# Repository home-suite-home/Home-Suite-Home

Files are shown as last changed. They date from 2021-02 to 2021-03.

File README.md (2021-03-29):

# Home-Suite-Home

# Product Vision
  Our product, Home Suite Home is for anyone that lives in a home or manages properties remotely. With our product, users can track a multitude of metrics inside and out of the home. As well as, have the piece of mind their investment is protected with real time alerts when anything out of the ordinary occurs. Great for when the user cannot be there in person. Home Suite Home supplies a wide range of sensing devices covering the environment and health of the home. The sensors and software are designed using off the shelf components and open source software to allow for easy access and infinite customizability. Our product differs from competitors such as Nest and SensorSuite by placing a focus on overall property health. It would focus more on providing analytics on the usage of utilities that are found inside the home, providing the potential to catch issues before they occur, saving the user from expensive repairs. This is the perfect tool for property or building managers, homeowners and even hobbyists to take control over their home’s data and bring it all together in one convenient, powerful place.

  ## Team Members
  * Matthew Dowdy - dowdyma1
  * Andres Graterol - graterollin
  * Wyatt Vining - wv040
  * David Crumley - daviejones
  * Nathan Moulton - NathanM117

# Sprint 1

## Materials
* [Trello Board](https://trello.com/b/BFcwvt3p/project) (Backlogs and Requirements)
* [Requirements](artifacts/requirements.md)
* [Velocity Chart](https://docs.google.com/spreadsheets/d/1tpRyT-jUgHkrLnwx5NcxtOvh3uGg8ddGYrl60E0q6DA/edit#gid=0)
* [Burndown Chart for Sprint 1](https://docs.google.com/spreadsheets/d/1tpRyT-jUgHkrLnwx5NcxtOvh3uGg8ddGYrl60E0q6DA/edit#gid=2030454987)

## Task Allocation
* Andres Graterol (graterollin) - requirement chart
* David Crumley (daviejones) - velocity chart
* Matthew Dowdy (dowdyma1) - burndown chart
* Wyatt Vining (wv040) - Trello Board
* Nathan Moulton (NathanM117) - product backlog

# Sprint 2

## Materials
* [Trello Board](https://trello.com/b/BFcwvt3p/project) (Backlogs and Requirements)
* [Velocity Chart](https://docs.google.com/spreadsheets/d/1tpRyT-jUgHkrLnwx5NcxtOvh3uGg8ddGYrl60E0q6DA/edit#gid=0)
* [Burndown Chart for Sprint 2](https://docs.google.com/spreadsheets/d/1tpRyT-jUgHkrLnwx5NcxtOvh3uGg8ddGYrl60E0q6DA/edit#gid=1102031550)
* [System Architecture](artifacts/architecture.md)
* [Product Demonstration](https://youtu.be/opssn2ocK3U)

## Task Allocation
* Andres Graterol (graterollin) - Requirement Chart/ UI
* David Crumley (daviejones) - Architecture/Class Diagrams
* Matthew Dowdy (dowdyma1) - UI / Velocity & Burndown Charts / Design Doc
* Wyatt Vining (wv040) - Sensor Prototype / Demo Video / Architecture
* Nathan Moulton (NathanM117) - Design Doc/Architecture Diagrams

# Sprint 3

## Materials
* [Trello Board](https://trello.com/b/BFcwvt3p/project) (Backlogs and Requirements)
* [Velocity Chart](https://docs.google.com/spreadsheets/d/1tpRyT-jUgHkrLnwx5NcxtOvh3uGg8ddGYrl60E0q6DA/edit#gid=0)
* [Burndown Chart for Sprint 3](https://docs.google.com/spreadsheets/d/1tpRyT-jUgHkrLnwx5NcxtOvh3uGg8ddGYrl60E0q6DA/edit#gid=571215391)
* [System Architecture](artifacts/architecture.md)
* [Testing](https://github.com/home-suite-home/Home-Suite-Home/tree/main/testing)
* [Product Demonstration](https://youtu.be/FdkxHIFB3po)

## Task Allocation
* Andres Graterol (graterollin) - Automated unit tests / Requirements
* David Crumley (daviejones) - EmailComponent / EmailCommandHandler
* Matthew Dowdy (dowdyma1) - UI / Charts
* Wyatt Vining (wv040) - Sensor Values Intake / Demo Video
* Nathan Moulton (NathanM117) - Database Setup and Testing

# Sprint 4

## Materials
* [Trello Board](https://trello.com/b/BFcwvt3p/project) (Backlogs and Requirements)
* [Velocity Chart](https://docs.google.com/spreadsheets/d/1tpRyT-jUgHkrLnwx5NcxtOvh3uGg8ddGYrl60E0q6DA/edit#gid=0)
* [Burndown Chart for Sprint 4](https://docs.google.com/spreadsheets/d/1tpRyT-jUgHkrLnwx5NcxtOvh3uGg8ddGYrl60E0q6DA/edit#gid=1480462962)
* [System Architecture](artifacts/architecture.md)
* [Testing](https://github.com/home-suite-home/Home-Suite-Home/tree/main/testing)
* [Product Demonstration](https://youtu.be/R36tOa5FSI4)

## Task Allocation
* Andres Graterol (graterollin) - Automated & Manual Testing
* David Crumley (daviejones) - Email Sensor Data Reporting
* Matthew Dowdy (dowdyma1) - UI & Charts
* Wyatt Vining (wv040) - Demo Video / Sensor Config / Raspberry Pi Setup
* Nathan Moulton (NathanM117) - Database Functionality & Testing

# Sprint 5

## Materials
* [Trello Board](https://trello.com/b/BFcwvt3p/project) (Backlogs and Requirements)
* [Velocity Chart](https://docs.google.com/spreadsheets/d/1tpRyT-jUgHkrLnwx5NcxtOvh3uGg8ddGYrl60E0q6DA/edit#gid=0)
* [Burndown Chart for Sprint 5](https://docs.google.com/spreadsheets/d/1tpRyT-jUgHkrLnwx5NcxtOvh3uGg8ddGYrl60E0q6DA/edit#gid=994440609)
* [System Architecture](artifacts/architecture.md)
* [Testing](https://github.com/home-suite-home/Home-Suite-Home/tree/main/testing)
* [Product Demonstration](https://youtu.be/gygcMzER3ZE)

## Task Allocation
* Andres Graterol (graterollin) - Automated Testing (UI & timeKeeper) / Manual Testing (Database)
* David Crumley (daviejones) - Data analytics email response (in development)
* Matthew Dowdy (dowdyma1) - UI
* Wyatt Vining (wv040) - Raspberry Pi upgrade / Database Stress Test / Timestamps / Sensor Config Data / Sensor Polling - Save Data / Sample Database Creation
* Nathan Moulton (NathanM117) - Database.py/ Manual Testing (Database)/ Sample Database Creation/ Timestamps

## Quick Links
* [System Source Code](source)
* [Sensor Source Code](sensor_source)
* [Testing](testing)
* [User Interface](source/email_ui.py)

# Sprint 6

## Materials
* [Trello Board](https://trello.com/b/BFcwvt3p/project) (Backlogs and Requirements)
* [Velocity Chart](https://docs.google.com/spreadsheets/d/1tpRyT-jUgHkrLnwx5NcxtOvh3uGg8ddGYrl60E0q6DA/edit#gid=0)
* [Burndown Chart for Sprint 6](https://docs.google.com/spreadsheets/d/1tpRyT-jUgHkrLnwx5NcxtOvh3uGg8ddGYrl60E0q6DA/edit#gid=428674570)
* [System Architecture](artifacts/architecture.md)
* [Testing](https://github.com/home-suite-home/Home-Suite-Home/tree/main/testing)
* [Product Demonstration](https://youtu.be/VESqYKWHarw)

## Task Allocation
* Andres Graterol (graterollin) - Developed and updated Automated Tests / Manual Testing
* David Crumley (daviejones) - Analytics / Email Response
* Matthew Dowdy (dowdyma1) - UI / Charts
* Wyatt Vining (wv040) - Encryption / Sensor Header Files / Manual Testing
* Nathan Moulton (NathanM117) - Development and Testing for Database

## Quick Links
* [System Source Code](source)
* [Sensor Source Code](sensor_source)
* [Testing](testing)
* [User Interface](source/User_Interface.py)

# Sprint 7

## Materials
* [Trello Board](https://trello.com/b/BFcwvt3p/project) (Backlogs and Requirements)
* [Velocity Chart](https://docs.google.com/spreadsheets/d/1tpRyT-jUgHkrLnwx5NcxtOvh3uGg8ddGYrl60E0q6DA/edit#gid=0)
* [Burndown Chart for Sprint 7](https://docs.google.com/spreadsheets/d/1tpRyT-jUgHkrLnwx5NcxtOvh3uGg8ddGYrl60E0q6DA/edit#gid=1633691467)
* [System Architecture](artifacts/architecture.md)
* [Testing](https://github.com/home-suite-home/Home-Suite-Home/tree/main/testing)
* [Product Demonstration](https://youtu.be/Fo_0uUr3R5Y)

## Task Allocation
* Andres Graterol (graterollin) - Developed and updated Automated Tests
* David Crumley (daviejones) - Email_Driver / Interactive Graphs
* Matthew Dowdy (dowdyma1) - UI / Charts
* Wyatt Vining (wv040) - Sensor Email Alerts / Conversions / Global Settings / Sensor Creation and Modeling / Demo Video
* Nathan Moulton (NathanM117) - Database.py / Install Scripts

## Quick Links
* [System Source Code](source)
* [Sensor Source Code](sensor_source)
* [Testing](testing)
* [User Interface](source/User_Interface.py)

# Sprint 8

## Materials
* [Trello Board](https://trello.com/b/BFcwvt3p/project) (Backlogs and Requirements)
* [Velocity Chart](https://docs.google.com/spreadsheets/d/1tpRyT-jUgHkrLnwx5NcxtOvh3uGg8ddGYrl60E0q6DA/edit#gid=0)
* [Burndown Chart for Sprint 8](https://docs.google.com/spreadsheets/d/1tpRyT-jUgHkrLnwx5NcxtOvh3uGg8ddGYrl60E0q6DA/edit#gid=335631044)
* [System Architecture](artifacts/architecture.md)
* [Testing](https://github.com/home-suite-home/Home-Suite-Home/tree/main/testing)
* [Product Demonstration](https://youtu.be/5nkZvYmcQeU)

## Task Allocation
* Andres Graterol (graterollin) - Automated Unit Tests / Project Presentation PowerPoint 
* David Crumley (daviejones) - installation and run script / Bug Fixes
* Matthew Dowdy (dowdyma1) - UI / Charts
* Wyatt Vining (wv040) - Sensor 3D Models / Sensor Arduino Code / Bug Fixes / Product Demo Video
* Nathan Moulton (NathanM117) - Database + Testing

## Quick Links
* [System Source Code](source)
* [Sensor Source Code](sensor_source)
* [Testing](testing)
* [User Interface](source/User_Interface.py)

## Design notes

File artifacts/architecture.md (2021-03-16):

# Program Organization
Home-Suite-Home is an open-source sensor suite. It is designed to be lightweight, modular home
analytics suite that provides home-owners and property managers a platform to monitor the health of their properties through the useof smart sensors. On a high level of operation, the sensors are responsible for sending data to a localised database hosted by a server/agregator. The sever portion stores data for time-series representaton, and the aggregator portion observes values in real time to verify that sensor readings are within user defined parameters. The user will recieve notfications via email in the event of any data anomalies, or when requested for data snapshots or historical data.

# Code Design
## System Context Diagram
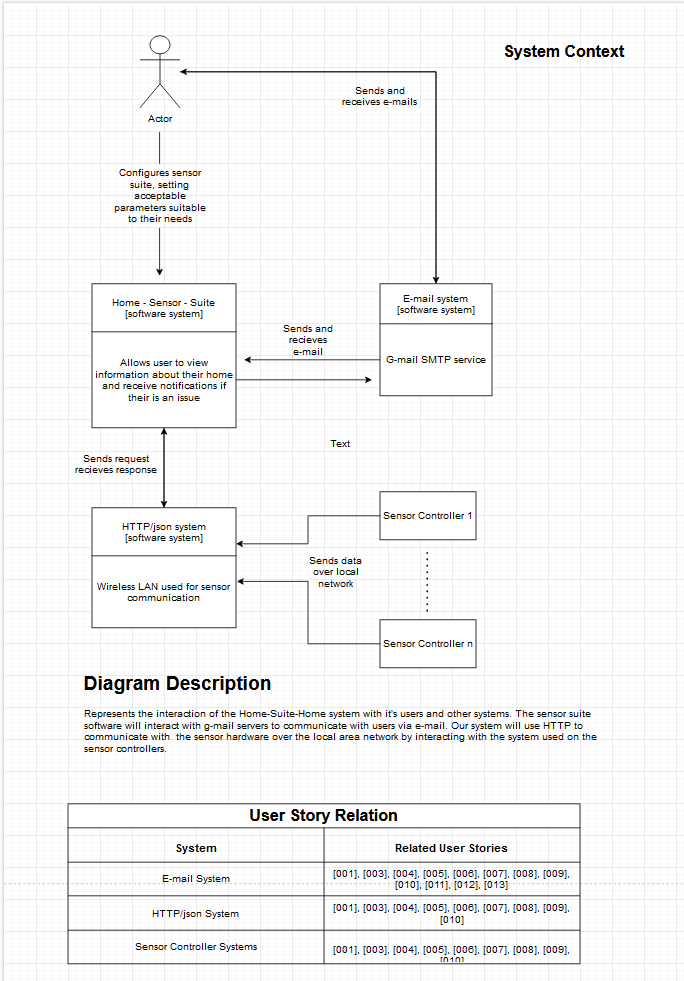
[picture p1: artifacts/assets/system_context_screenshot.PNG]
screenshot of system context diagram


## Container Diagram
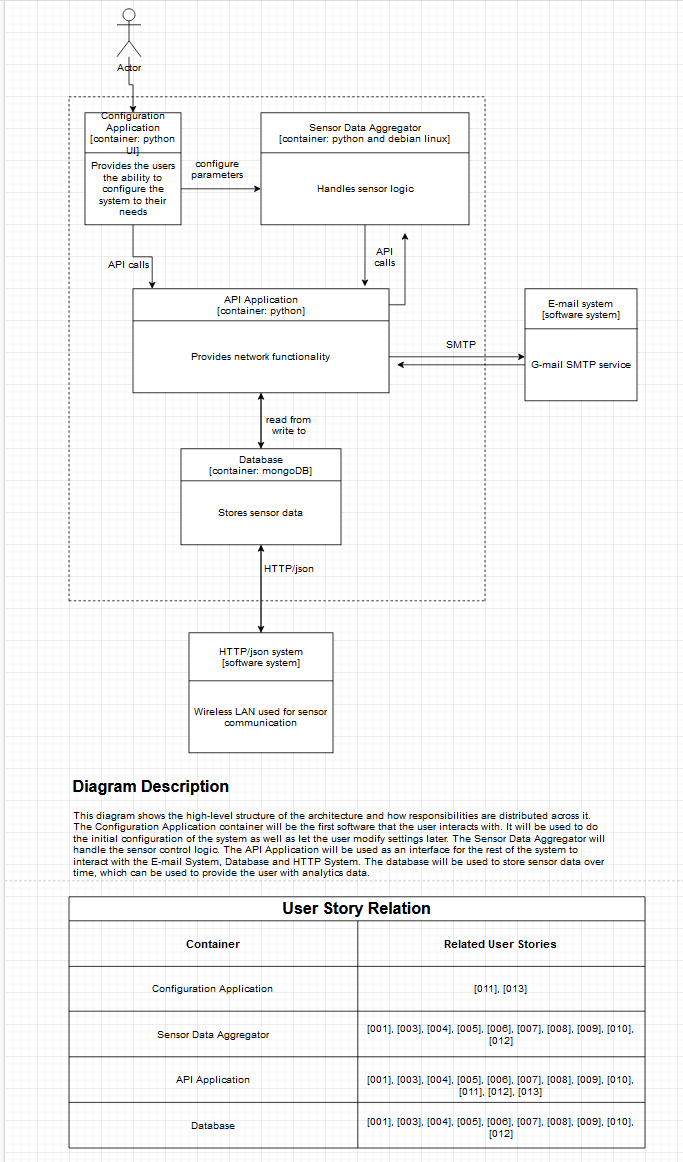
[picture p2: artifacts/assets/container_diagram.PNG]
screenshot of container diagram


## Component Diagrams
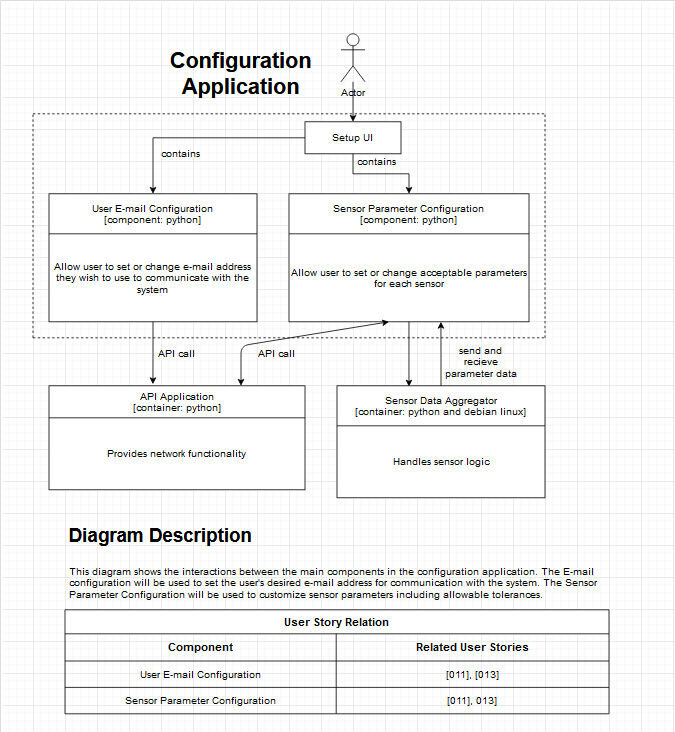
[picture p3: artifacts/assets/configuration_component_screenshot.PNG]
screenshot of configuration application

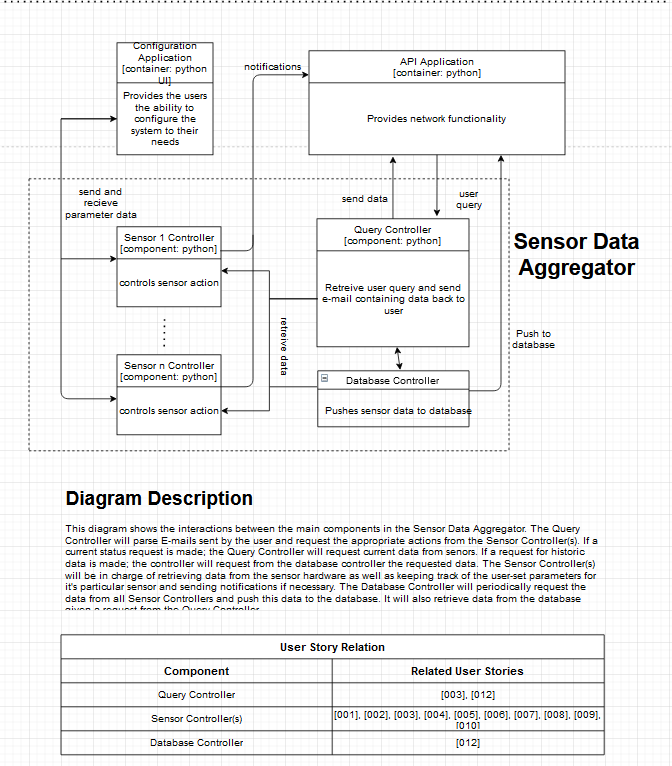
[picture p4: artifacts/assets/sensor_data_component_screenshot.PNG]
screenshot of sensor data aggregator

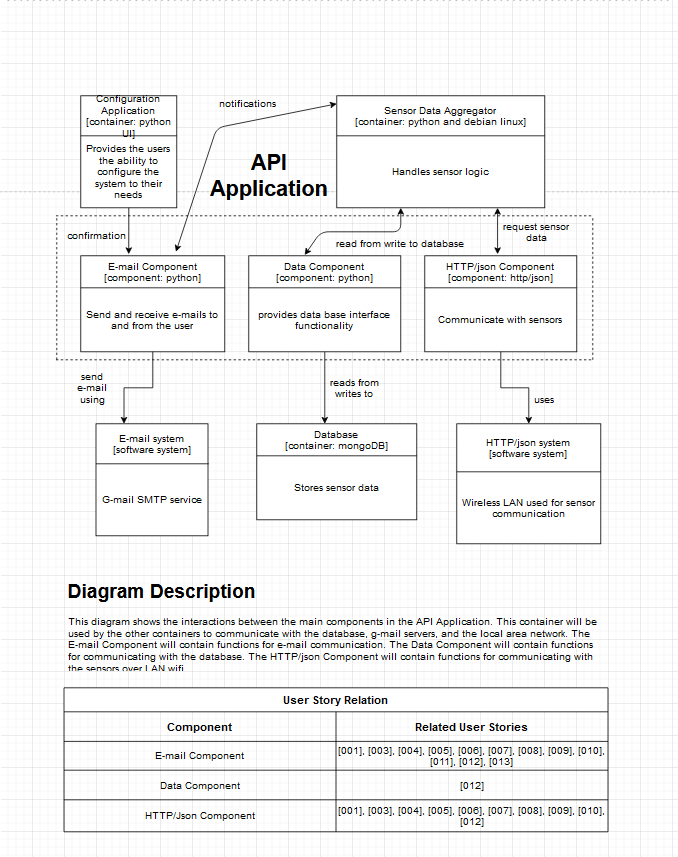
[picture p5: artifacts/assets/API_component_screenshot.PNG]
screenshot of API


## Class Diagrams
### EmailComponent
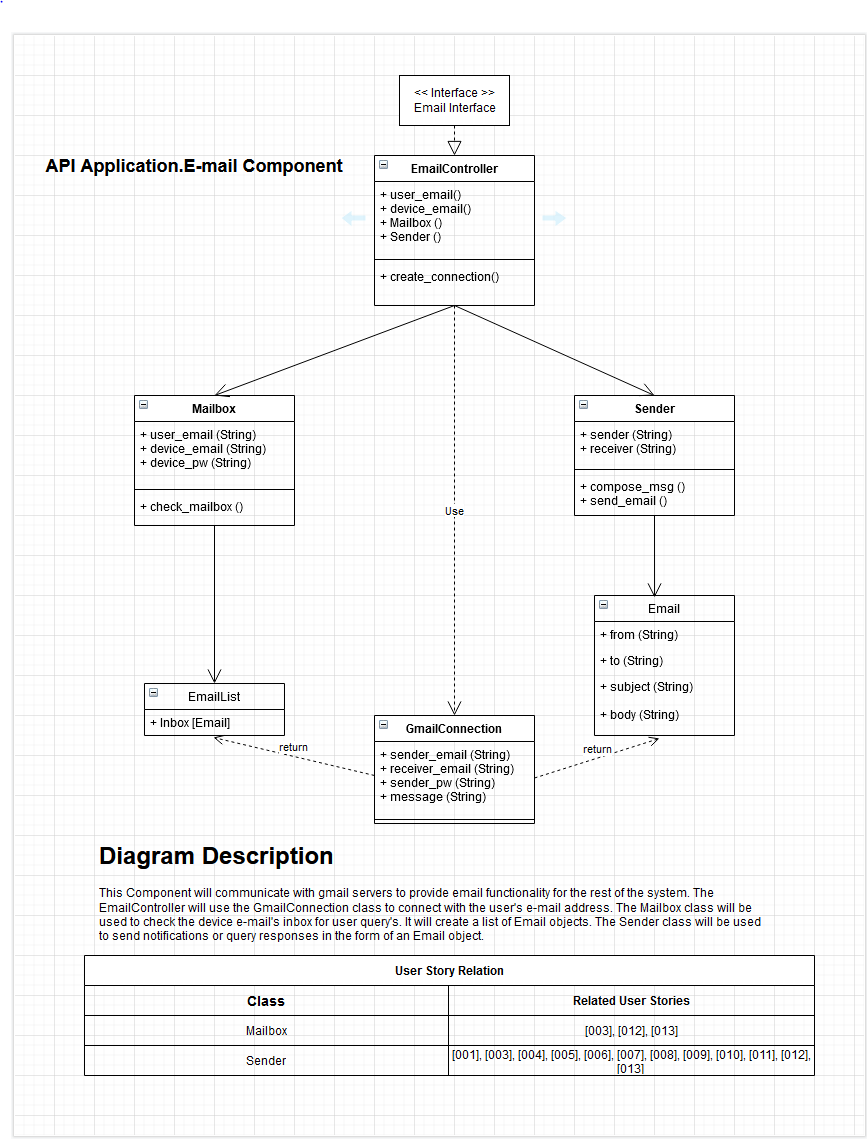
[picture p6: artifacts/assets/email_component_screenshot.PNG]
screenshot of email component class diagram

### EmailCommandHandler
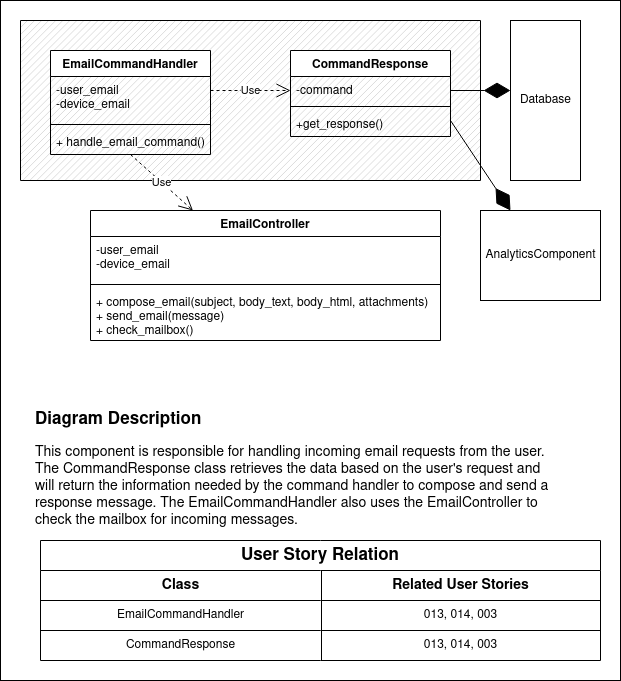
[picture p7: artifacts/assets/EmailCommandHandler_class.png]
screenshot of EmailCommandHandler class diagram

### AnalyticsComponent
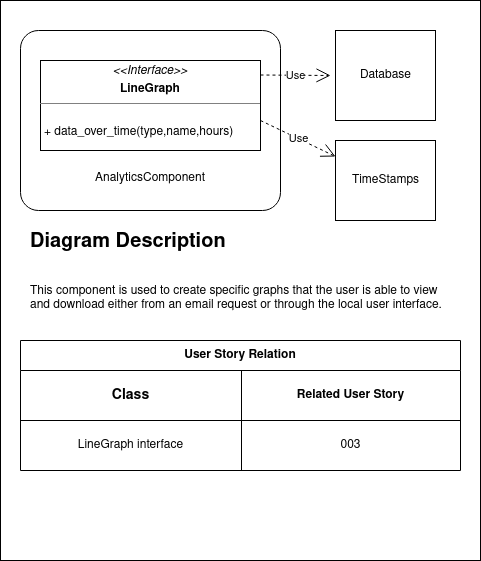
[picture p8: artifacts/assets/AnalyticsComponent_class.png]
screenshot of AnalyticsComponent class diagram

### Sensors.py
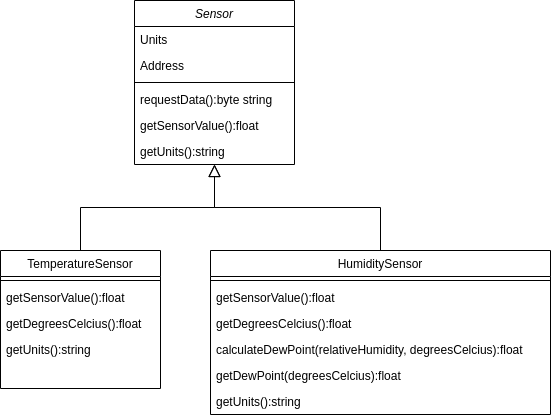
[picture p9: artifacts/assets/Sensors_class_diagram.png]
Screenshot of Sensors.py class Diagram

#### Diagram Description:
This component is used to retrieve sensors data over the network. The Sensors class is responsible for requesting the base data of any sensor. The TemperatureSensor and HumiditySensor classes extend the functionality of the Sensor class and provide specific units and conversions based on the type of data received.
| Class | Related User Stories (UID) |
| --- | --- |
| Sensor | 002, 017, 022 |
### timeKeeper.py
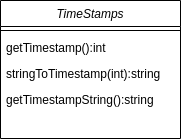
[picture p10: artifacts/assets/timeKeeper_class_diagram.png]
Screenshot of timeKeeper.py class Diagram

#### Diagram Description:
This component provides utilities for parsing and using time and date stamps. The function getTimestamp() returns an integer value representing the current time. This is useful as a format for storing the timestamp in the database. Then we can use stringToTimestamp() to convert the stored timestamp back into a readable format.
| Class | Related User Stories (UID) |
| --- | --- |
| TimeStamps | 020 |
### encryption.py
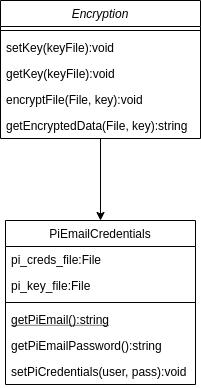
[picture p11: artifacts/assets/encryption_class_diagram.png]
Screenshot of timeKeeper.py class Diagram

#### Diagram Description:
The class encryption provides functions to generate, store and retrieve a secure key. Also, encrypt and decrypt a file using the secure key. The PiEmailCredentials class extends that functionality to specifically save and retrieve the email credentials for the Pi itself.
| Class | Related User Stories (UID) |
| --- | --- |
| TimeStamps | 028 |

# Data Design
Much of the data stored in this database will be unstructured. Sensors like the temperature/humidity sensor won't have many relations with one another. There are some sensor types that may have relational attributes, such as the RFID sensors which will require a table of valid IDs...

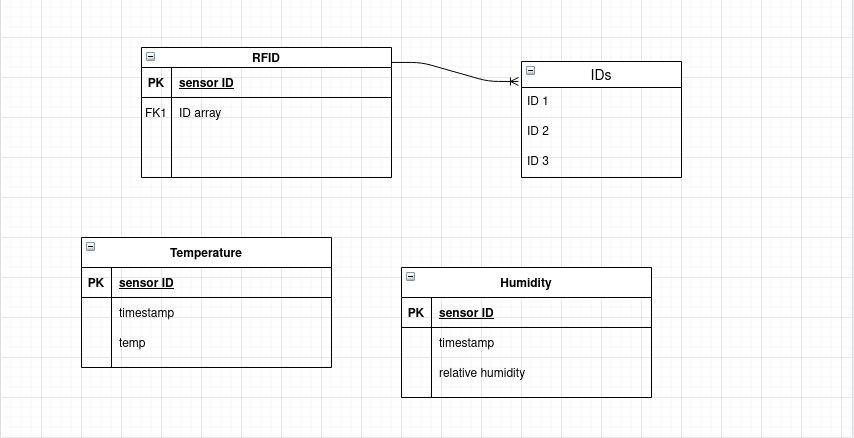
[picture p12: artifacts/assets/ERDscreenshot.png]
screenshot of ERD


# Business Rules
- The system should record new sensor data every 30 seconds.
- The user should be able to add new sensors after initial setup through the GUI.
- The system should be able to store at least a year's worth of sensor data. This should be
calculated with a 'standard' sensor collection.

# User Interface Design
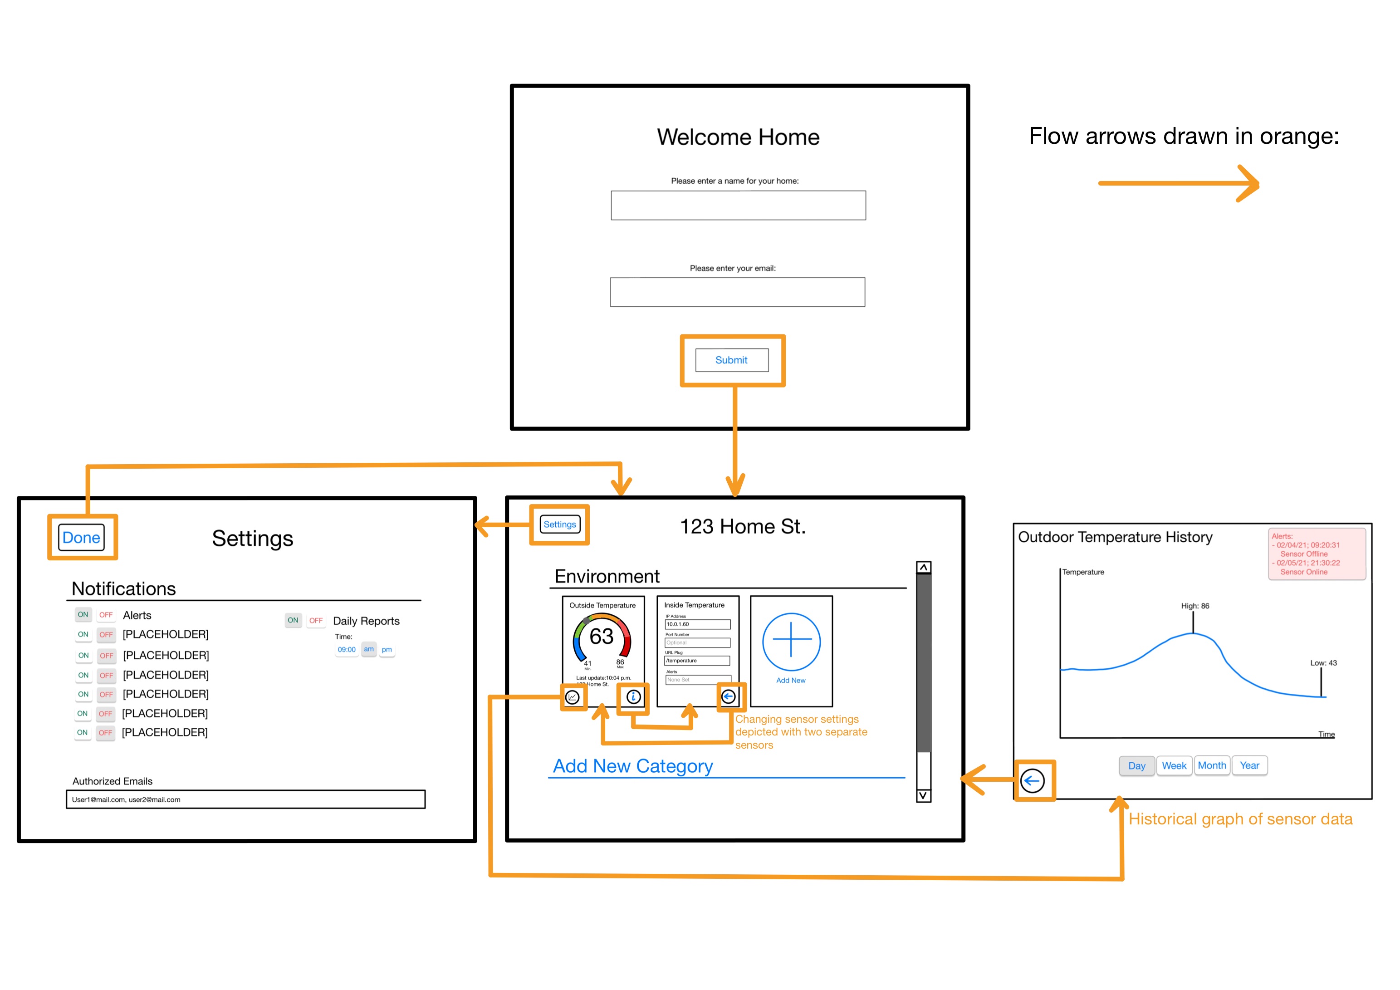
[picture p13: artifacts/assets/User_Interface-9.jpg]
UI Map Diagram

The purpose of this screen is to get the user's email so that the Raspberry
Pi knows where to send updates and statistics about the user's system.

After plugging in the Raspberry Pi to power and ethernet, the user makes sure they are on the same wifi network as the RaspberryPi and types in the
IP address `127.0.0.1:8050` into their browser. The user then uses the mouse to click on the text box, and then they type their
email. Once the user presses submit, a confirmation email is sent to the user so that they know that sending an email works.

| Window Number | UID |
|---|-----|
| 1 | 011 |

# Resource Management
Computational load is divided among several ESP8266 modules with 2.5GHz processors, and a
Raspberry Pi 3 with 2Gb of RAM. The Pi is responsible for running the main script for the aggregator, hosting the GUI and related config files, as well as hosting the database for the sensors. Further research is needed to determine the exact workload and resource requirements.

# Security
This solution is designed to focus on ease of access and utility to the open-source community.
That said software security is not a primary concern for our implementation. The architecture of the system however, lends itself to being rather secure in practice. All traffic occurs over the local network, and so the data saved within the database is not seen except by those on said network.

# Performance
Our system is designed to run using low cost hardware such as, Raspberry Pi's. With recent advancements in these types of computers, performance should not be a concern. Our limitations may be considered as the hardware limitations of the entry level Raspberry Pi ([Technical Specifications](https://www.raspberrypi.org/products/raspberry-pi-4-model-b/specifications/)). Further, our system is designed to use a polling approach to sensor data collection. Meaning, the data can be collected and analyzed at the rate the aggregator (Raspberry Pi) becomes available. Lastly, the NodeMCU ESP8266 boards used to send sensor data should only be required to send their data at most every seccond which is well within their performance capabilities.

# Scalability
The user will be able to add extra sensors up to a point, so as to provide greater breadth of analytics. The open source nature of our system lends itself to creating potentially limitless additional sensors and control systems. A single instance of the system can serve only proprty due to the localised nature of operation. Multiple properties may be monitored by setting up an aggregator server at each loction.

# Interoperability
The sensors are responsible for sharing data with the database as well at the aggregator. The aggregator is responsible for receiving and responding to email requests from a user.

# Internationalization/Localization
Our implimentation is localized. All string handling will be ASCII and English. This may be modified in the future as the software is open source.

# Input/Output
The primary input/output(I/O) for our system will be HTTP requests between the aggregator and sensor modules. The I/O will be real-time. When a request is made, the receiver processes and sends a response to the requester. If the response is unexpected, the aggregator will handle the error as appropriate.

# Error Processing
This solution focuses on monitoring sensor data and keeping the user informed. Should an error occur, the system may first attempt to correct it. For example, if a sensor does not respond, the request may be resent. In the case the error may not be corrected, the user will be notified via email and may take appropriate action. Also, any important information will be logged to a local file on the aggregator should an error occur.

# Fault Tolerance
The system is designed to continue to run through a multitude of faults. For example, if a sensor is unavailable or not working properly, the aggregator will continue to log all other sensors and check periodically to see if the issue with that sensor has been resolved. The system may also enter an alternate method of operation given a critical failure. As long as the aggregator is powered on and connected to the network, a user may still request email reports from the system. These reports may be ammended to reflect errors in the system.

# Architectural Feasibility
The architecture of our system is intended to grow into future features. This allows the architecture design to start out as feasible. With room to add features as the core system is developed.

# Overengineering
Our system is designed to continue to run through many issues. There is a one single point failure: the aggregator. If the aggregator encounters a hardware or power failure, the system will no longer function as intended. It is important to note that even without the aggregator the sensors can still be queried by HTTP requests from within the network.

# Build-vs-Buy Decisions
### Libraries Used
* Dash
* ESP8266WiFi
* ESP8266WebServer
* Wire
* Adafruit_SHT31

*This section will continue to be updated as more code is added with the sprints to come...*

# Reuse
We intend to use some open source libraries mentioned in the Build-vs-Buy Decisions. This code, where possible, will be built into functions that can be replaced in the event we pivot to different libraries. Beyond that, we currently have no intention to reuse code. This is subject to change as we progress though the design process. We will update this document should any changes arise.

*italic* This section will continue to be updated as more code is added with the sprints to come...

# Change Strategy
The system is intended to be modular and adaptable. New sensors and their data can be added simply at any point in the future. We also intend to build the core functionality in a way that allows the base system to persist through many different perturbations of the higher level features. This will be accomplished by using simple, single responsibility functions and delineating data files between versions.

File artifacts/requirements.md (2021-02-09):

# Requirements 

| Requirement ID | User Story ID | Requirement | Acceptance Criteria | Effort | Priority | Status |
|---|---|---|---|---|---|---|
| 000 | DEV 001 | The burndown chart shall contain an "ideal line" of 45 degrees  | The "ideal line" is present and is at a downward 45 degree slope from the top left of the chart | 2 | Necessary | Verified |
| 001 | DEV 001 | The burndown chart shall contain the actual line depicting the team's work in a weekly sprint | The actual line is present and accurately depicts the work done by the team during the sprint | 2 | Necessary | Verified |
| 002 | DEV 001 | The burndown chart will have a y-axis that consists of the story points per sprint | The burndown chart has a y-axis consisting of the story points | 2 | Necessary | Verified |
| 003 | DEV 001 | The burndown chart will have an x-axis that consists of the number of days per sprint | The burndown chart has an x-axis consisting of the number of days per sprint | 2 | Necessary | Verified |
| 004 | DEV 002 | The velocity chart shall have a column for planned amount of story points to be completed during the sprint | The velocity chart has a column for the planned amount of story points to be completed during the sprint | 1 | Necessary | Verified |
| 005 | DEV 002 | The velocity chart shall have a column for the actual amount of story points to completed during the sprint | The velocity chart has a column for the actual amount of story points to completed during the sprint | 1 | Necessary | Verified |
| 006 | DEV 002 | The velocity chart will have a y-axis that consists of the number of story points planned for the sprint | The velocity chart has a y-axis consisting of the number of story points planned for the sprint | 1 | Necessary | Verified |
| 007 | DEV 002 | The velocity chart will have an x-axis that consists of the sprint number | The velocity chart has an x-axis consisting of the sprint number | 1 | Necessary | Verified |
| 008 | DEV 003 | The developers shall set up a virtual linux environment | All developers can run and push a simple "hello, world" program | 1 | Necessary | Verified |
| 009 | DEV 004 | The requirements chart shall have columns for: Requirement ID, User Story ID, Requirement, Acceptance Criteria, Efffort, Priority, and Status | The requirements chart has columns for the specified elements | 1 | Necessary | Verified |
| 010 | DEV 005 | The trello board shall reflect the product backlog | The trello board contains the product backlog | 1 | Necessary | Verified |
| 011 | DEV 005 | The trello board shall reflect the sprint backlog | The trello board contains the sprint backlog | 1 | Necessary | Verified |
| 012 | DEV 005 | The trello board shall contain columns for keeping updates such as: planning, working, testing, and done | The trello board contains columns for planning, working, testing, and done | 1 | Necessary | Verified |
| 013 | DEV 006 | The developers shall create a smtp hello world program | When the script is run an email is created and sent out | 2 | Necessary | Verified |  
| 014 | DEV 007 | New burndown and velocity charts shall be made for sprint 2 | The new sprint 2 burndown and velocity charts have been created, and are available to access from github | 1 | Necessary |  Verified |
| 015 | DEV 008 | The architecture diagram shall contain context, container, and component diagrams | The architecture diagram is comprised of context, container, and component diagrams | 3 | Necessary | Verified |
| 016 | DEV 008 | The architecture diagram shall include a description and explanation of each diagram within it | The architecture diagram includes a description and explanation of each diagram within it | 3  | Necessary | Verified |
| 017 | DEV 008 | The architecture diagram shall include a table that relates each block to one or more user stories | The architecture diagram includes a table that relates each block to one or more user stories | 3 | Necessary | Verified |
| 018 | DEV 009 | The UML class diagram shall display the classes along with the interactions between them | The UML class diagram displays the classes along with the interactions between them | 2 | Necessary | Verified |
| 019 | DEV 009 | Each UML diagram shall be accompanied by a brief description explaining what the elements are and why they are in the diagram | Each UML diagram is accompanied by a brief description explaining what the elements are and why they are in the diagram | 2 | Necessary | Verified |
| 020 | DEV 009 | The class diagram shall include a table that relates each class to one or more user stories | The class diagram includes a table that relates each class to one or more user stories |  2 | Necessary | Verified |
| 021 | DEV 010 | The complete design document shall include elaboration for business rules, resource management, security, performance, scalability, interoperability, internationalization/localization, input/output, error processing, fault tolerance, architectural feasability, overengineering, build-vs-buy decisions, reuse, and chang strategy | The complete design document has all fields covered and is shown in github |  4 | Necessary | Verified |
| 022 | DEV 011 | The temperature sensor hooked up to the ESP8266 shall output data on a web browser | The sensor value information can be viewed from a web browser within the Local Area Network |  2 | Necessary | Verified |
| 023 | 011 | The user interface shall be able to register a user's email information | The user will receive an email confirmation | 4 | Necessary | Verified |
| 024 | DEV 013 | The video demonstration shall showcase the temperature sensor and a basic UI | The video demonstrates the functionality of the temperature sensor and a basic UI in roughly two minutes | 2 | Necessary | Verified |

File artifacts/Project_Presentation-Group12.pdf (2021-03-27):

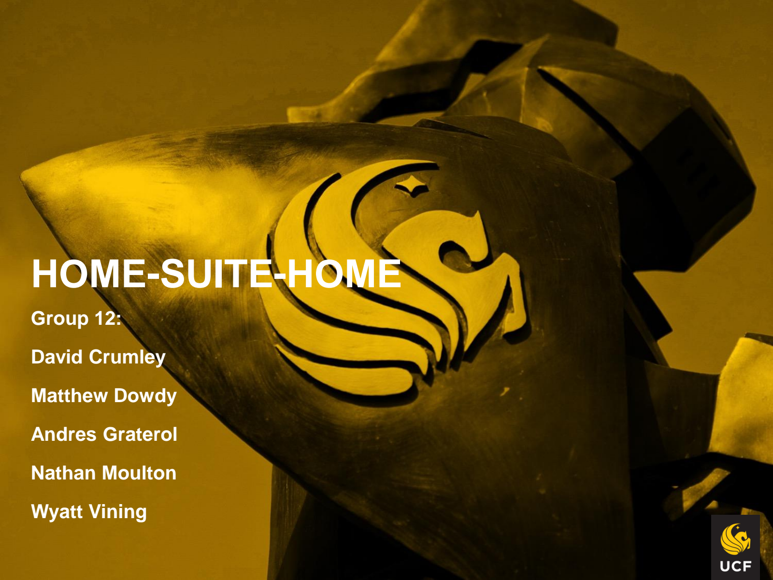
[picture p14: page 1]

# HOME-SUITE-HOME

Group 12:

David Crumley

Matthew Dowdy

Andres Graterol

Nathan Moulton

Wyatt Vining

# Purpose & Motivation

Home-Suite-Home was designed with the intention of providing a method for property owners to remotely view the status of their properties. The properties would be installed with multiple sensors that could be easily accessed using a User-Interface and email system. With Home-Suite-Home installed into the homeowner’s properties, the customer would never have to worry about what is happening while they are away!

# System Alternatives

Our Competitors:
- Google Nest Hub
- This system provides an interconnection of smart devices around the home. Google Hub has compatibility with devices such as security cameras, smart lights, and speakers.
- Samsung SmartThings Hub
- This system provides an interconnection of smart devices around the home. It comes with a companion mobile application and allows for the addition of other Samsung brand smart devices such as motion sensors and water leak detectors.
Us:
Since our system is open-source, it eliminates the need for such high installation and maintenance costs associated with the competition. There is no subscription necessary, and users have the ability to configure and add their own sensors. Unlike our competitors, Home-Suite-Home allows the user to add sensor of any type. In comparison to the other systems, our sensor suite is focused on providing the user with information solely on property health. In addition to this, we have real-time analytics so that the customer can view a full history of all their desired sensors. The ability to add sensors on the fly, view real-time data, and receive real-time alerts is what makes Home-Suite-Home rise above the competition.

# Core Features

### This system boasts: - An email system that can make requests to the database running on a raspberry pi and receive responses in return. The email also receives alerts when any sensor is out of range of the user-defined

tolerance.

### - Analytics that show the history of all the sensors either through

email commands or through button presses on the user-interface.

### - A user-interface that contains: - A settings page to enter the raspberry pi credentials, user emails, silence alerts, and enter desired data refresh rate and

notification rate.

### - A home screen that allows users to add, edit, and delete sensors. Each card also allows the user to view the analytics

for the specific sensor.

# Technologies

- Git and Github for version control.

### - Raspberry Pi 4V+ to aggregate all of the sensor data and host the

database.
- MongoDB to host the database server.
- Plotly to display the analytics graphs.
- Dash to assist in the creation of the user-interface.

### - VNC Viewer - Languages used: Python, C++, Bash Script, HTML, CSS - Arduino: NodeMCU V12E for each sensor - Sensors (written in Arduino C++):

- Temperature
- Humidity
- Leak detection
- Light
- Pressure
- Range

# Algorithms

- For handling email commands:
- Every 30 seconds the script gets all user emails from the database.
- For each user email check the system mailbox for a message received by the user.
- If a message has been received, create a response based on the contents of the email. Send the response to the user.
- For Data Analytics:
- In the case of a single graph:
- Get data from database based on the requested sensor’s parameters.
- If no data is returned: return a None object.
- Convert the received data based on the user’s specified unit preference.
- Iterate over all the data , removing NaN values and calculating a cumulative average.
- If only NaN data is found: return a None object.
- Obtain the max and min from the resulting data set.
- Create a plotly graph object:
- Add each trace (data, avg, min, max) to the graph object.
- Add titles and return to the graph object.

# Algorithms Continued

- For populating the User Interface:
- The callback: create_new_card:
- The script gets the state of the sensor parameters (name, type, ip, port, etc…).
- The callback is activated when the create button is pressed.
- Upon button press, a new config entry in the database is created using the sensor’s entered fields.
- Sends a message to set_card_container to update the screen.
- set_card_container:
- Reads all data from the config collection in the database.
- Outputs sensor cards to the screen corresponding to the config entries.
- For populating the User Interface:
- For connecting with the sensors:
- A sensor object is instantiated with a URL, port and plug corresponding to where the sensor can be found on the network.
- Address for the sensor is assembled in the format: http://IP_ADDRESS:PORT/plug.
- Upon requesting sensor value:
- If the sensor is unavailable NaN is returned in place of a sensor value.
- Otherwise, sensor value is sent to the requested location.

# Algorithms Continued

- For generating and sending alerts:
- The alert object is instantiated with a copy of the sensor’s config data and its current value.
- The database is checked to see if an alert was previously logged within the rate limit.
- If no log exists, the script generates an email to send.
- The script loops the users registered in the database collection and sends an alert to each of them.
- The script saves a log to the database to reset the rate limit.
- For settings:
- This script uses python’s ConfigParser to parse INI files.
- The INI files will contain the necessary data for sensor polling rate and notification rate limit.
- If the file cannot be read, -1 is returned.
- For running the sensors:
- Script begins by retrieving the set sensor poll rate and whether or not the user has chosen to silence alerts from the settings.config file.
- If not poll rate has been specified. The script settles for the default value of 60 seconds.
- A while loop runs while the system is active.
- For each iteration, the existing sensor config data is pulled from the database. The retrieved sensor value is compared against the corresponding min and max range if alerts are turned on.
- Alerts are sent if necessary.
- New sensor values are changed to the database.
- While loop waits the sensor poll rate time before running once again.

# Algorithms Continued

- For the sensor hardware template:
- A setup function will run as soon as the Arduino with the sensor is powered on.
- The device attempts to connect to the user’s network.
- The sensor is initialized using functions from the sensor manufacturer’s library.
- The URL plug is specified – this is how the sensor data will actually be retrieved.
- Script generates a response to a sensor value request.
- If no URL plug is specified, the root page is reached, and an error message is passed to the client.
- For the Database:
- The script receives the IP and port of the mongodb server process and establishes a connection from which functions can be carried out.
- The script uses the functions found in the pymongo library to make the necessary database queries.
- If a database collection is attempted to be read from, but none exists, then the collection is created within the script.

# Future Plans

### - We would hope to split the user interface into different categories

of sensors.
- We would like to expand the list of default supported sensors.
- We would like to add quality-of-life changes to the User-Interface.

### - We want to add more notifications that get sent to the user – such as alerting the user when a sensor goes offline and needs to be

serviced.

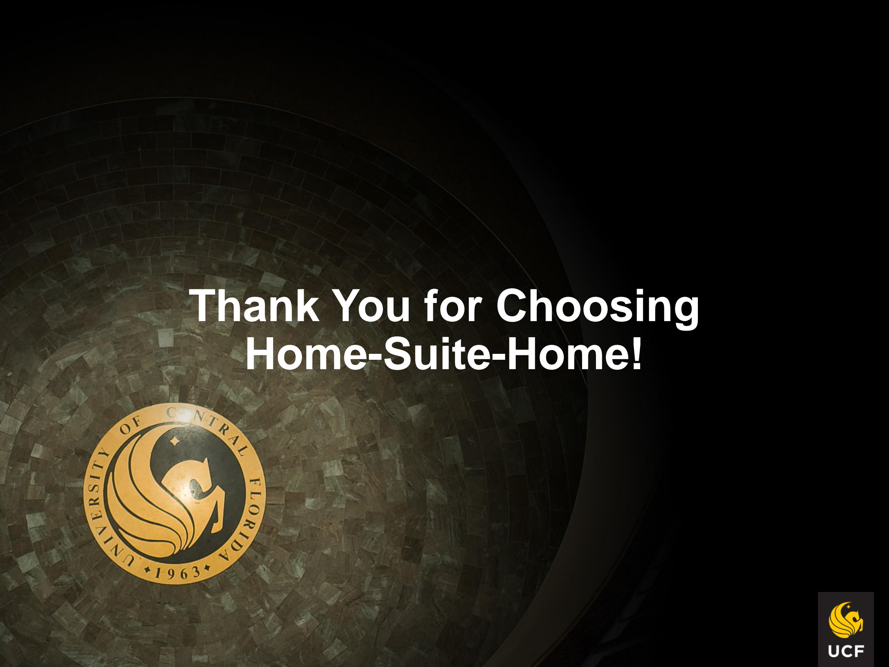
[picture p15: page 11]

# Thank You for Choosing Home-Suite-Home!

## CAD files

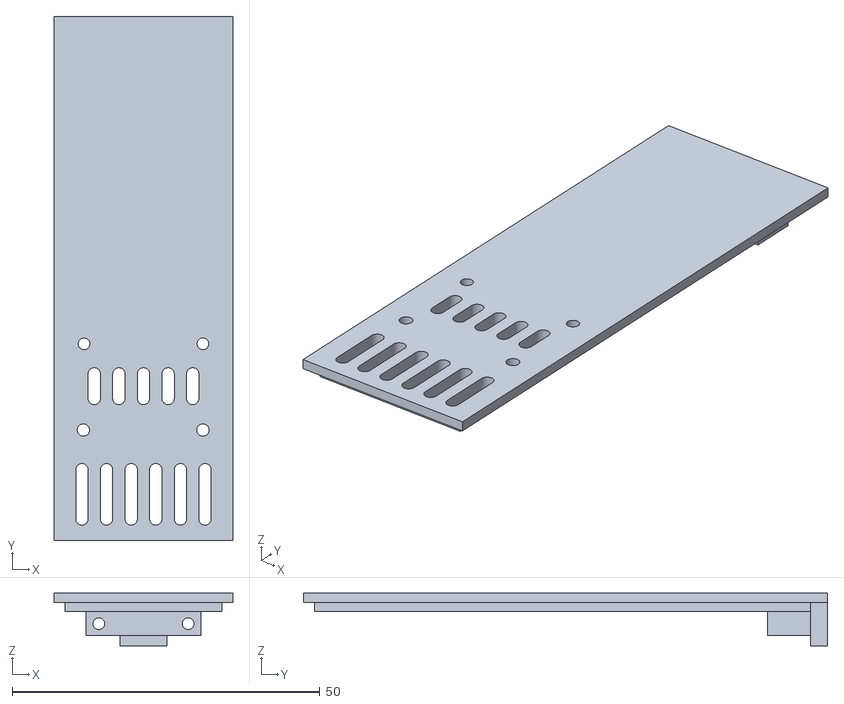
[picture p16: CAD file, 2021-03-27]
sensor_3D_models/lid^SHT31_extended.STL
29.0 x 85.1 x 8.54

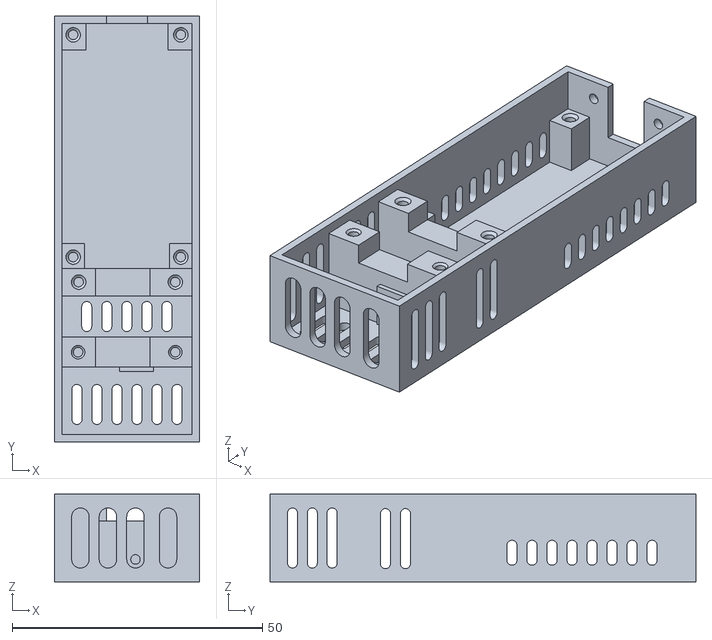
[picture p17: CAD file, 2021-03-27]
sensor_3D_models/box^SHT31_extended.STL
29.0 x 85.1 x 17.5

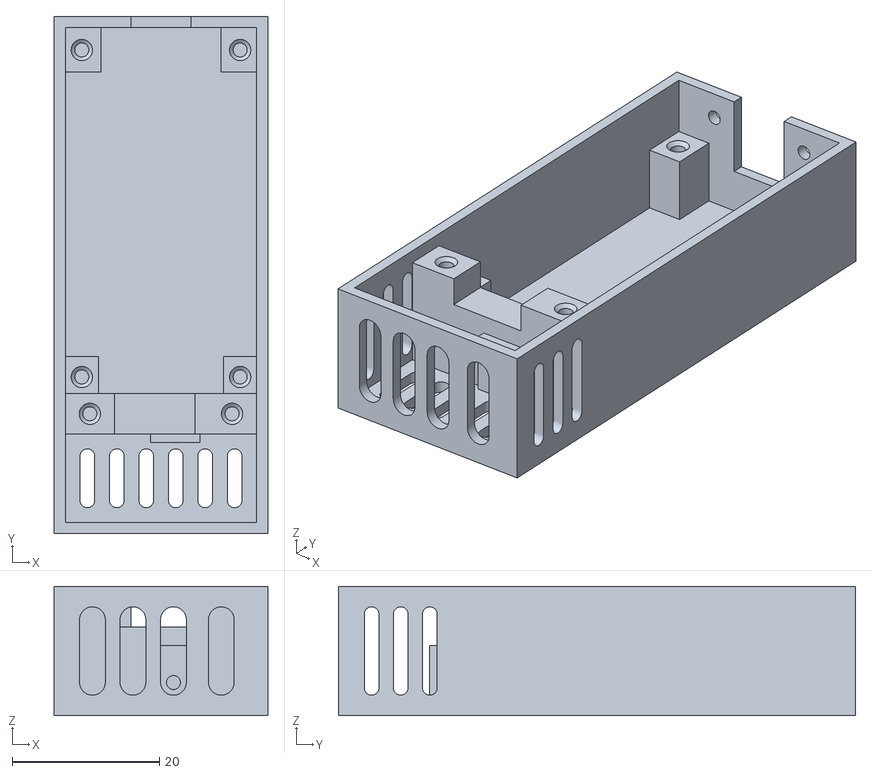
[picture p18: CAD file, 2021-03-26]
sensor_3D_models/box^SHT31_Temperature_Humidity.STL
29.0 x 70.2 x 17.5

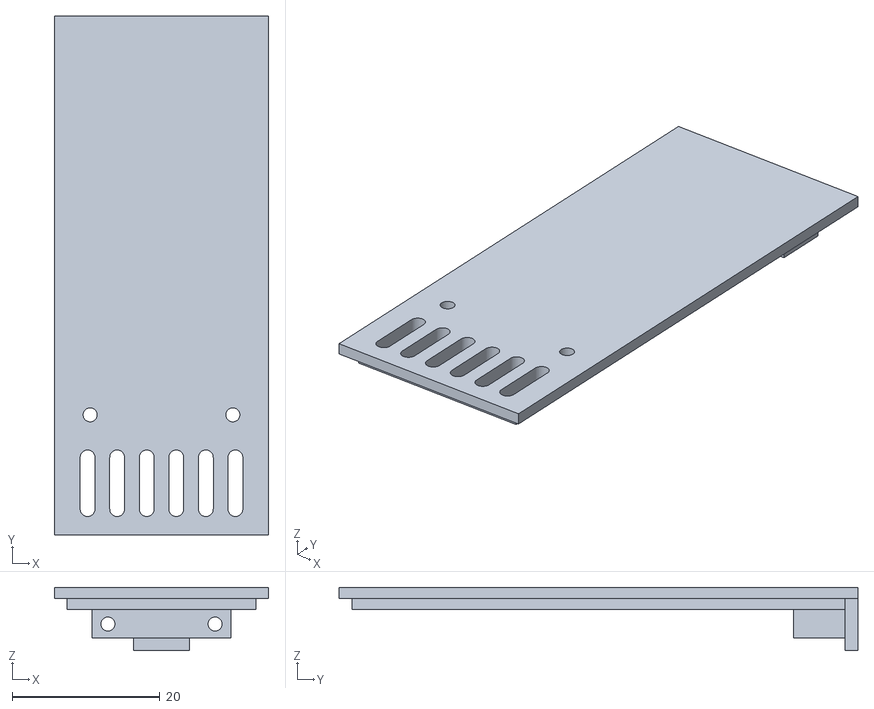
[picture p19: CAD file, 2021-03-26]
sensor_3D_models/lid^SHT31_Temperature_Humidity.STL
29.0 x 70.2 x 8.54

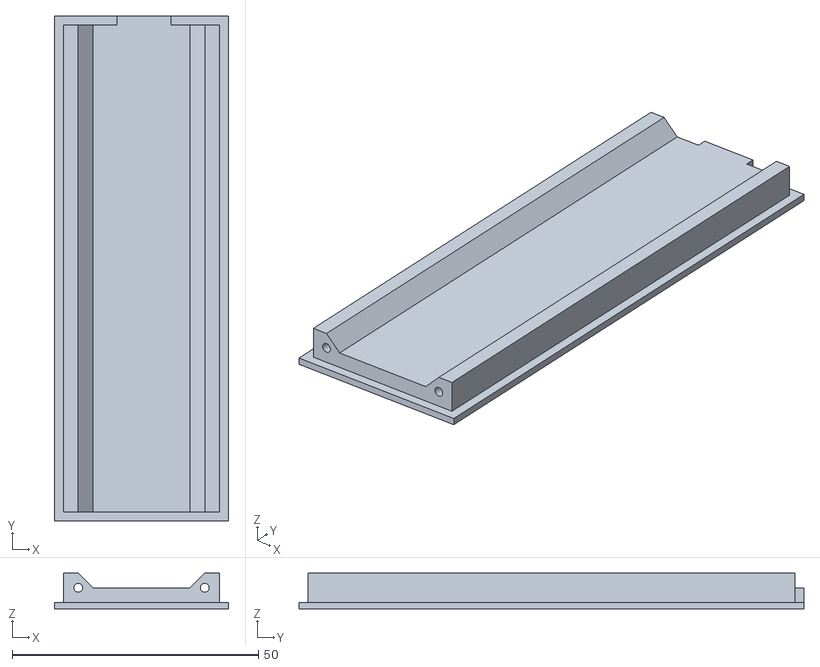
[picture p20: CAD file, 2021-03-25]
sensor_3D_models/lid^CO2_AQI_sensor.STL
35.4 x 102.5 x 7.30

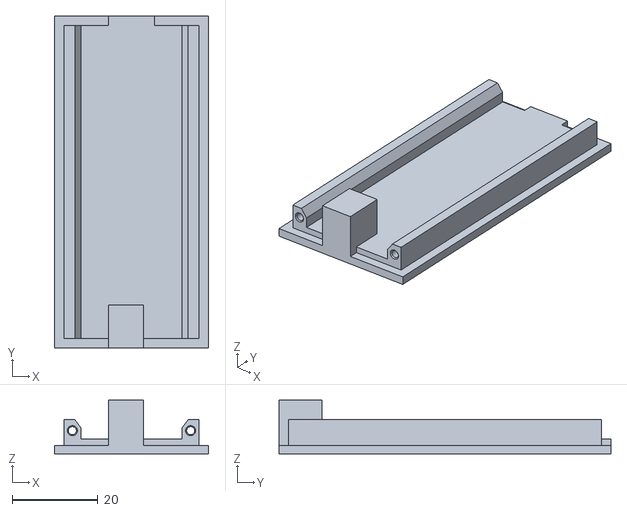
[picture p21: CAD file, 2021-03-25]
sensor_3D_models/lid^flow_temp.STL
36.0 x 77.5 x 12.5

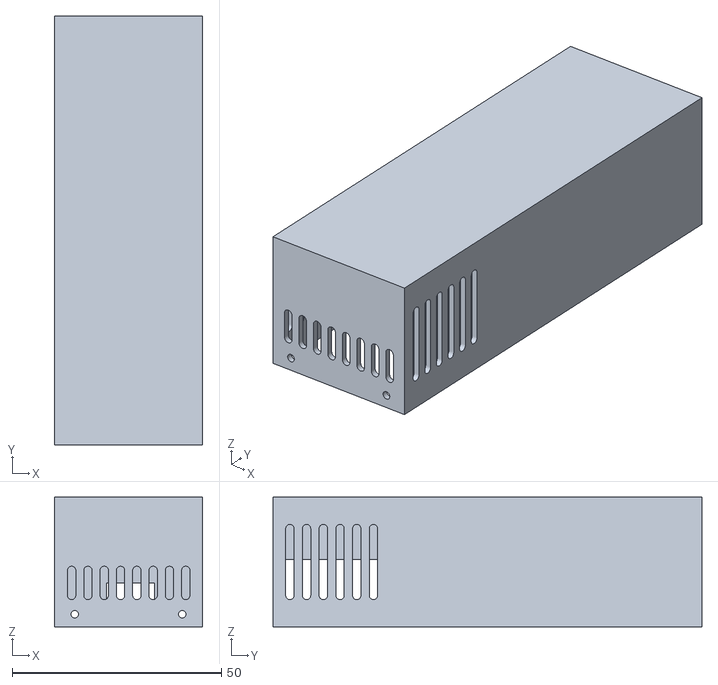
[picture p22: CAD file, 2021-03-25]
sensor_3D_models/box^CO2_AQI_sensor.STL
35.4 x 102.5 x 31.0

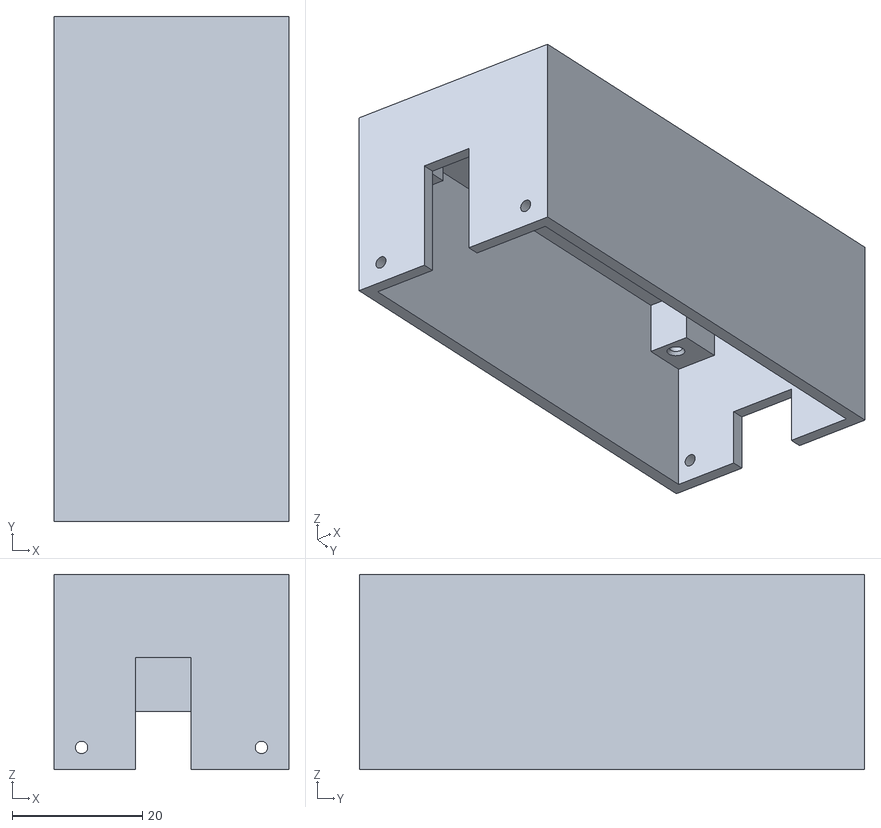
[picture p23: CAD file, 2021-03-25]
sensor_3D_models/box^flow_temp.STL
36.0 x 77.5 x 30.0

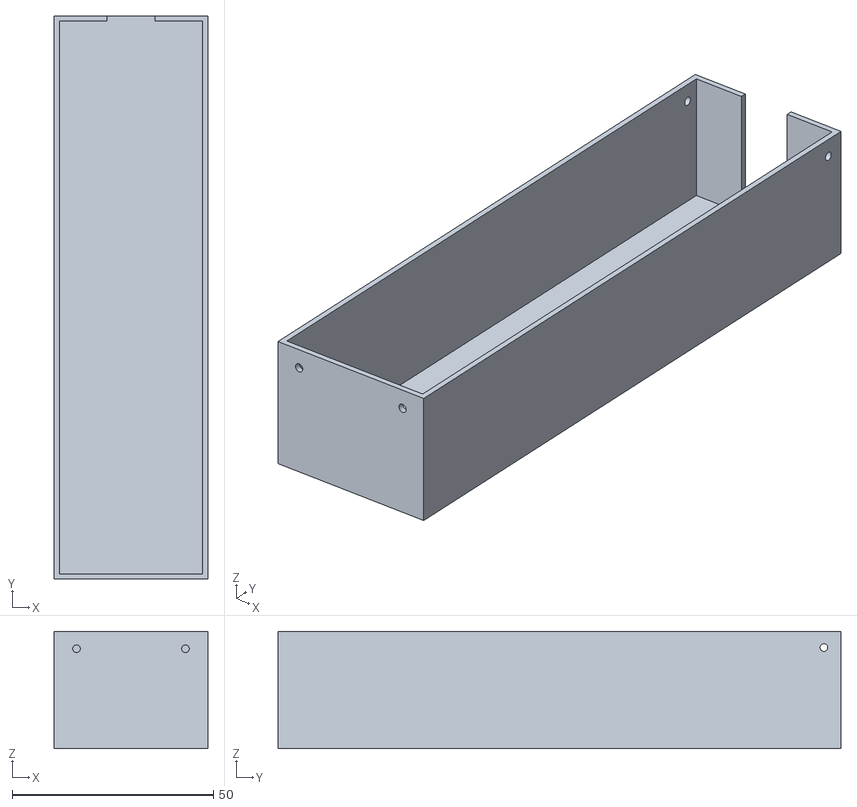
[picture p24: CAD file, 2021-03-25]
sensor_3D_models/Lid^leak_detector.STL
38.2 x 140.0 x 29.1

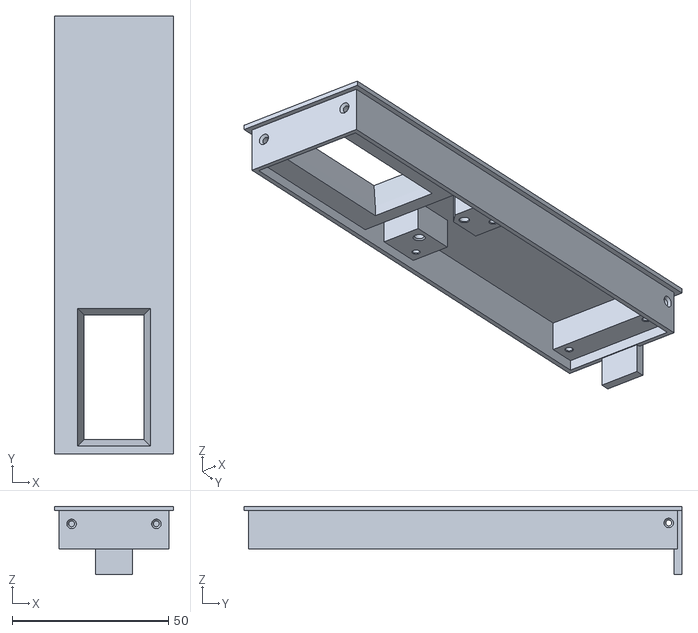
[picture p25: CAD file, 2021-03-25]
sensor_3D_models/base^leak_detector.STL
38.2 x 140.0 x 21.8

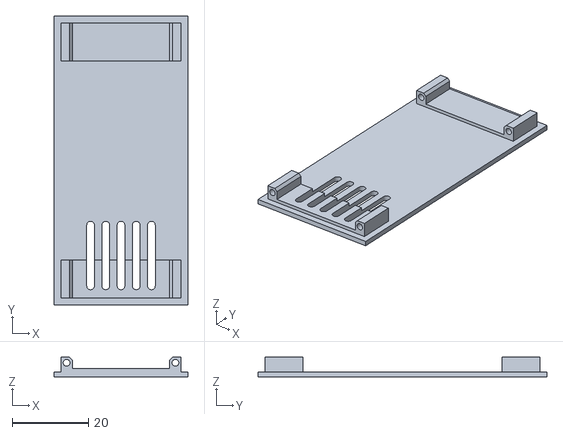
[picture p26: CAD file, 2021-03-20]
sensor_3D_models/barometeric_sensor - Lid^barometeric_sensor-1.STL
35.2 x 75.9 x 5.20

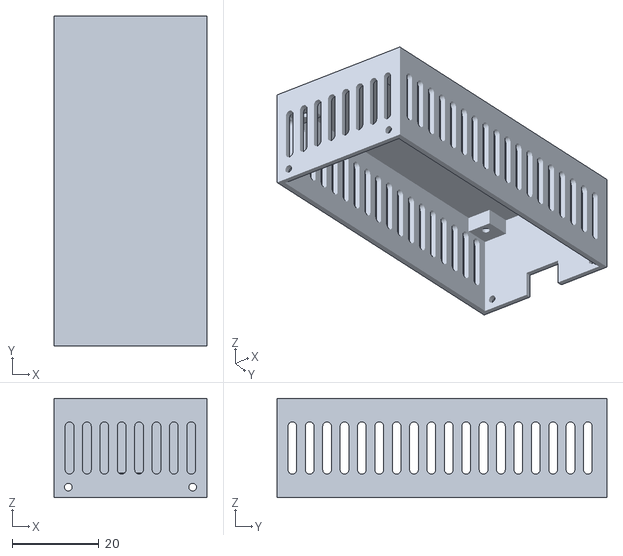
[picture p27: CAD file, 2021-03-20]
sensor_3D_models/barometeric_sensor - Bottom^barometeric_sensor-1.STL
35.2 x 75.9 x 22.8

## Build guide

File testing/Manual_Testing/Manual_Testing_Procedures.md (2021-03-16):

This file contains instructions for executing manual testing

# CommandHandlerTest.py
## Description
Verify *EmailCommandHandler.py* can properly respond to an email sent by a specified user
## Test Tools and Dependencies
The following will be needed for this test:
* Linux Command Line Terminal
* Python standard libraries

* clone the repository on to the local machine: this will ensure all necessary files are found

## Test Cases
### [U014] As a property owner I want to receive a response from the system when a command is given over email so that the system will do what I want remotely.
### Functional Case (help message)
**Test Status** *PASS*</br>
#### Test Procedures
| No. | Steps to Reproduce | Expected Behavior |
| --- | --- | --- |
| 1 | In the linux command line terminal, from the repo's main directory, move to the manual testing directory| cd |
| 2 | In the linux terminal, enter the command $python CommandHandlerTest.py | prompt |
| 3 | When prompted, enter the email address that will be used to communicate with the program | prompt |
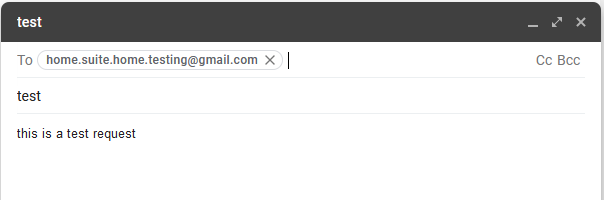
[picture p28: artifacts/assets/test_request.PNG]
test_request
| 4 | Using an email application, send an email to 'home.suite.home.testing@gmail.com' |  |

#### Test Results
| No. | Expected Results | Actual Results |
| --- | --- | --- |
| 1 | The terminal will reflect the operations being handled by the running program | terminal_response |
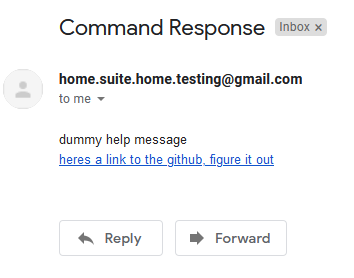
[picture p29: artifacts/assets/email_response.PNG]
email_response
| 2 | An email message will be recieved by 'home.suite.home.testing@gmail.com' |  |

### [U003] As a property owner, I would like to view a graphic representation of sensor data over time so that I can see trends in my property.
### Functional Case (get sensor data)
**Test Status** *PASS*</br>
#### Test Procedures
| No. | Steps to Reproduce | Expected Behavior |
| --- | --- | --- |
| 0 | Have a mongodb instance running locally on your machine | mongo |
| 1 | Import the test database into mongodb instance | import
| 2 | In the linux command line terminal, from the repo's main directory, move to the manual testing directory| cd |
| 3 | In the linux terminal, enter the command $python CommandHandlerTest.py | prompt |
| 4 | Using an email application, send an email to 'home.suite.home.testing@gmail.com' from 'home.suite.home.test.user@gmail.com'| test_request |

#### Test Results
| No. | Expected Results | Actual Results |
| --- | --- | --- |
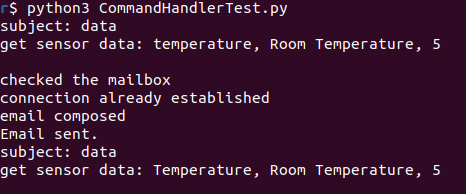
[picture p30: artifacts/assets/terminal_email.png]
terminal_response
| 1 | The terminal will reflect the operations being handled by the running program |  |
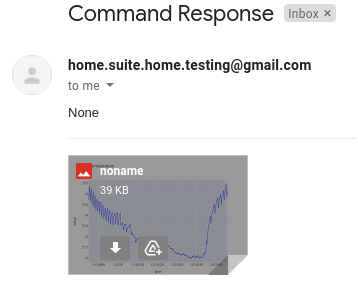
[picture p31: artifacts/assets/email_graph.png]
email_response
| 2 | An email message will be recieved by 'home.suite.home.testing@gmail.com' conatining an image of the data graph|  |

### Negative Case
**Test Status** *PASS*</br>
#### Test Procedures
| No. | Steps to Reproduce | Expected Behavior |
| --- | --- | --- |
| 1 | In the linux command line terminal, move to the directory (/testing/Manual_Testing) | cd |
| 2 | In the linux terminal, enter the command $python CommandHandlerTest.py | prompt |
| 3 | When prompted, enter an email address different than the one that will be used to communicate with the system | prompt |
| 4 | Using an email application, send an email to 'home.suite.home.testing@gmail.com' from the email used in the Functional Test| test_request |

#### Test Results
| No. | Expected Results | Actual Results |
| --- | --- | --- |
| 1 | The terminal will not show anything | terminal_response |
| 2 | An email message will not be recieved by 'home.suite.home.testing@gmail.com' | email_response |

# Sensors.py
## [U002] As a property-owner, I'd like the temperature of my property to be monitored.
## Description
Verify *Sensors.py* can properly access sensor data from a web server, convert units and display the results correctly.
## Test Tools and Dependencies
For this test, we are beginning with the following tools installed:
* Linux Text Editor (Or Similar Code Editing Tool)
* Linux Command Line

We will also need the source code we are testing as well as our test script:
* [Sensors.py](/source/HTTP_Component/Sensors.py)
* [sensorSim_constant.py](/testing/Manual_Testing/sensorSim_constant.py)

Note: For simplicity, move both source files into a test directory on the local machine.

## Test Cases
### Functional Case
**Test Status:** *PASS*

**Test Data:**
We will use *25.00* for our degrees Celsius and *50.00* percent for our relative humidity. These numbers are typical values for indoor room conditions.
| No. | Steps to Reproduce | Expected Behavior |
| --- | --- | --- |
| 1 | Open the directory containing both *Sensors.py* and *sensorSim_constant.py* | A folder containing both source files should appear on the screen |
| 2 | Right click in the directory window and select the *Open in Terminal* option | A terminal window will appear with the correct directory showing to the right of the users name |
| 3 | Right click in the directory window for a second time and again select the *Open in Terminal* option | A second terminal window should appear again showing the correct directory name to the right of the users name |
| 4 | In the first terminal window type *python3 sensorSim_constant.py* and press the return key | The terminal window will display the message *Server started ht<span>tp://</span>localhost:8080* |
| 5 | In the second terminal window type *python3 Sensors.py* and press return | The following output will be observed in the terminal: Sensor.py Nominal Output|
| 6 | Compare the temperature in degrees Fahrenheit from the terminal output from *Sensors.py* shown in step 5 to a known conversion from 25.00 degrees Celsius to Fahrenheit [WolframAlpha Temperature Conversion](https://www.wolframalpha.com/input/?i=25.00+Celsius+to+Fahrenheit) | The *Sensor.py* terminal output for degrees Fahrenheit will match the WolframAlpha reference value |
| 7 | Verify the relative humidity displayed in the terminal output from *Sensors.py* matches the test data of 50.0 | The relative humidity displayed in the terminal output for *Sensors.py* will match the test data value of 50.0 |
| 8 | Verify the dew point displayed in the *Sensors.py* terminal output matches the first three significant digits from right to left of the [reference value 56.9](https://www.calculator.net/dew-point-calculator.html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) | The dew point from the terminal output of *Sensors.py* will match the reference value |

### Negative Case
**Test Status:** *PASS*

**Test Data:**
No test data needed.
| No. | Steps to Reproduce | Expected Behaviour |
| --- | --- | --- |
| 1 | Open the directory containing both *Sensors.py* and *sensorSim_constant.py* | A folder containing both source files should appear on the screen |
| 2 | Right click the *Sensor.py* file and click on the *Open With Text Editor* option | A context menu will appear when the *Sensors.py* file is right clicked and when the *Open With Text Editor* option is left clicked from that menu, a text editor displaying the *Sensor.py* source code. |
| 3 | Scroll down to line 98 and change the word in parenthesis from *temperature* to *fail* | The word *temperature* is replaced with the word *fail* |
| 4 | Scroll down to line 103 and change the word in parenthesis from *temperature* to *fail* | The word *temperature* is replaced with the word *fail* |
| 5 | Left click save in the upper right corner of the text editor to save the modified version of *Sensors.py* | The modified *Sensor.py* file will be saved |
| 6 | Close the text editor | The text editor window will disappear |
| 7 | Open the directory containing both *Sensors.py* and *sensorSim_constant.py* | A folder containing both source files should appear on the screen |
| 8 | Right click in the directory window and select the *Open in Terminal* option | A terminal window will appear with the correct directory showing to the right of the users name |
| 9 | Right click in the directory window for a second time and again select the *Open in Terminal* option | A second terminal window should appear again showing the correct directory name to the right of the users name |
| 10 | In the first terminal window type *python3 sensorSim_constant.py* and press the return key | The terminal window will display the message *Server started ht<span>tp://</span>localhost:8080* |
| 11 | In the second terminal window type *python3 Sensors.py* and press return | The following output will be observed in the terminal: Sensor.py Nominal Output |
| 12 | Observe the error from step 11 causes a crash resulting from incorrectly formatted data. | This error is expected behavior and is slated to be revised in future versions. |

# Database_test.py
## [DEV015] As a developer, I want to be able to access the database in Python, so that I can use database functions in other python files.  
## Description
This test script works to interact with the MongoDB database that will house the records for all of our sensors. The purpose of this script is to prove that we have connection to the database and can make edits to it without going through the database's GUI.

## Testing Requirements and Dependencies
To set up a test environment in which to run the code, the following tools are required:

* Bash shell(or a similar Unix terminal emulator)
* [MongoDB Community Server](https://www.mongodb.com/try/download/community)
* [Database.py](/source/Server_Component/Database.py)
* [Database_test.py](/testing/Manual_Testing/Database_test.py)
* [timeKeeper.py](/source/timeKeeper.py)

Before running any of the programs listed here, it is recomended to follow the procedures for [setting up the server process for MongoDB](https://docs.mongodb.com/manual/administration/install-community/) on your operating system. If you want access to a GUI for the database, it is recommended that you choose to install on either macOS or Windows. Ensure that *Database_test.py*, *Databse.py*, and *timeKeeper.py* are in the same directory on your machine before running.

## Test Procedures

| No. | Steps to Reproduce | Expected Behavior |
| --- | --- | --- |
|  1  | Open the file *Database_test.py* on a text editor of your choice, and uncomment the lines db.clearConfigData() and db.clear() if they are not already. | The line will light up to indicate that it will be compiled when ran. |
|  2  | Open the terminal and procede to the directory containing the required files. | The directory should contain both files required for testing when inputting the commands *ls* or *dir* on the command line. |
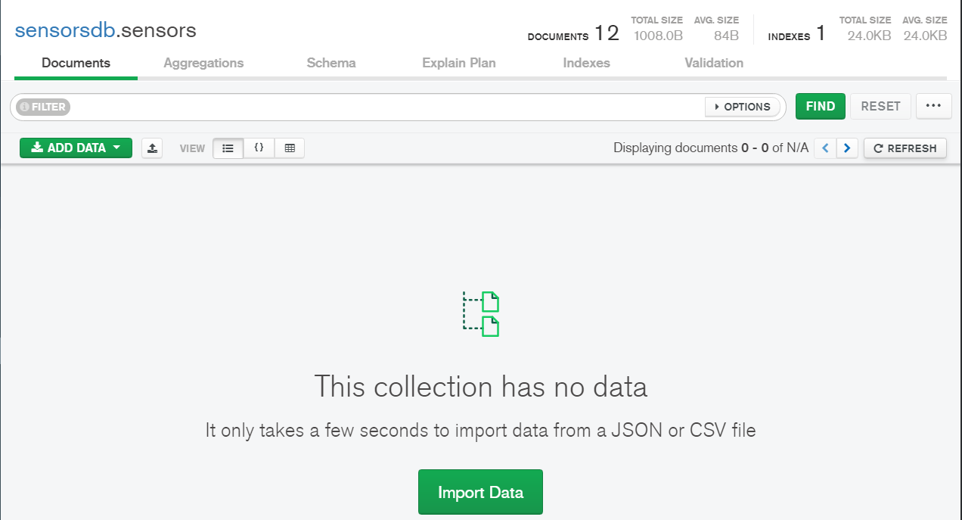
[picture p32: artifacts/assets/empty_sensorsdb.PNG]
empty
|  3  | Run the *Database_test.py* script | Upon opening the MongoDB GUI (if running on macOS or Windows) you should see an empty databse called *sensorsdb*  |
|  4  | Return to the *Database_test.py* file and now comment out the lines db.clearConfigData() and db.clear(). | The line should now appear commented out and it will not compile when ran in the command line. |
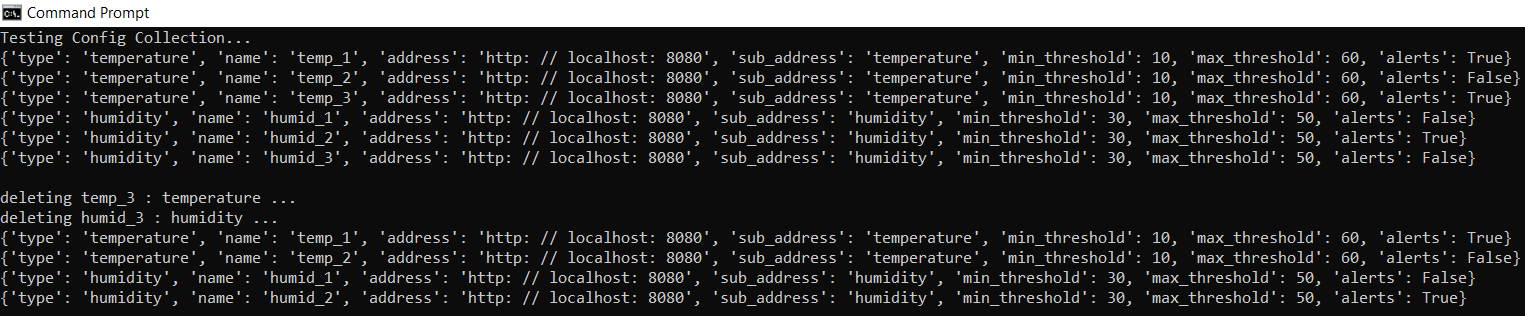
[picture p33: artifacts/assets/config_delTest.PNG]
configDel
|  5  | Run the testing script again. | The command line shall have a view of the config data before and after deleting elements from it.  |
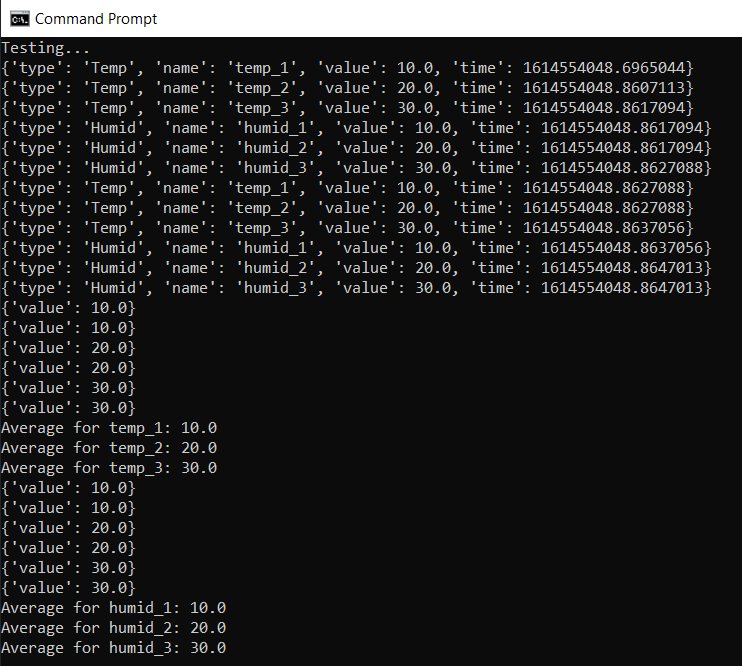
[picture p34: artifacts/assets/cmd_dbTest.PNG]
cmd
|  6  | Scroll down on the terminal. | The command line shall have have a view of all the records as a list and should also be printing the averages for each sensor.  |
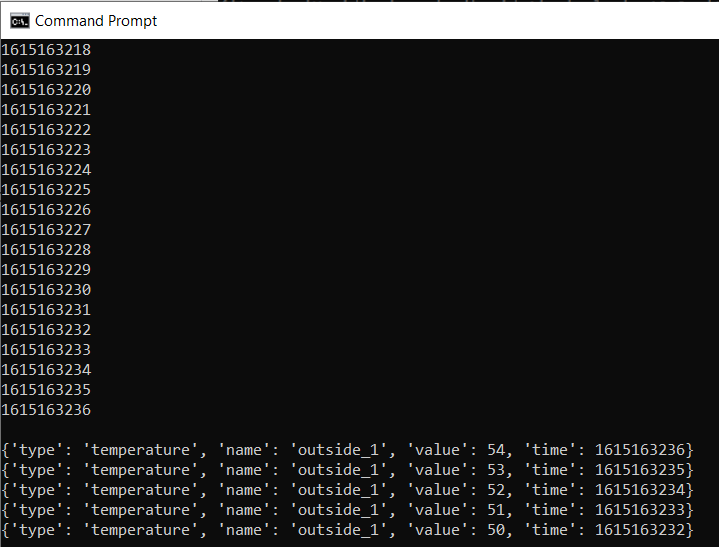
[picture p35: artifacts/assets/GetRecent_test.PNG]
recent
|  7  | Scroll down on the terminal. | The terminal shall show 20 timestamps strings in epoch time. It will also show the 5 most recent objects passed to the database and their corresponding epoch time. |
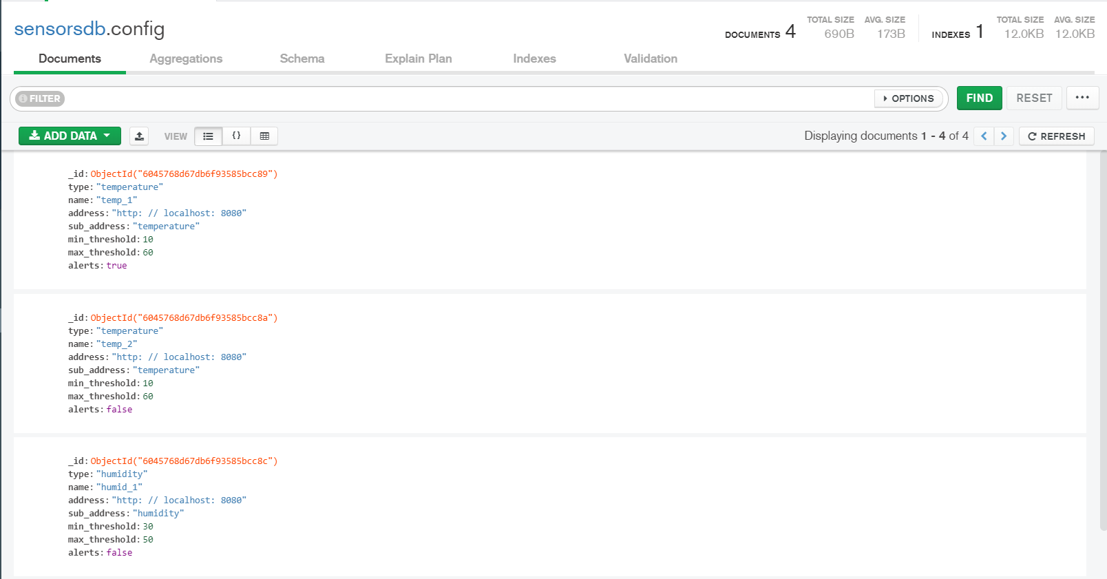
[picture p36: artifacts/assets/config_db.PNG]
config
|  8  | Check the Database once again. Two collectons should be added. Click the one named *config*.  | The database should be populated with the sensor configuration data sent in the testing file! |
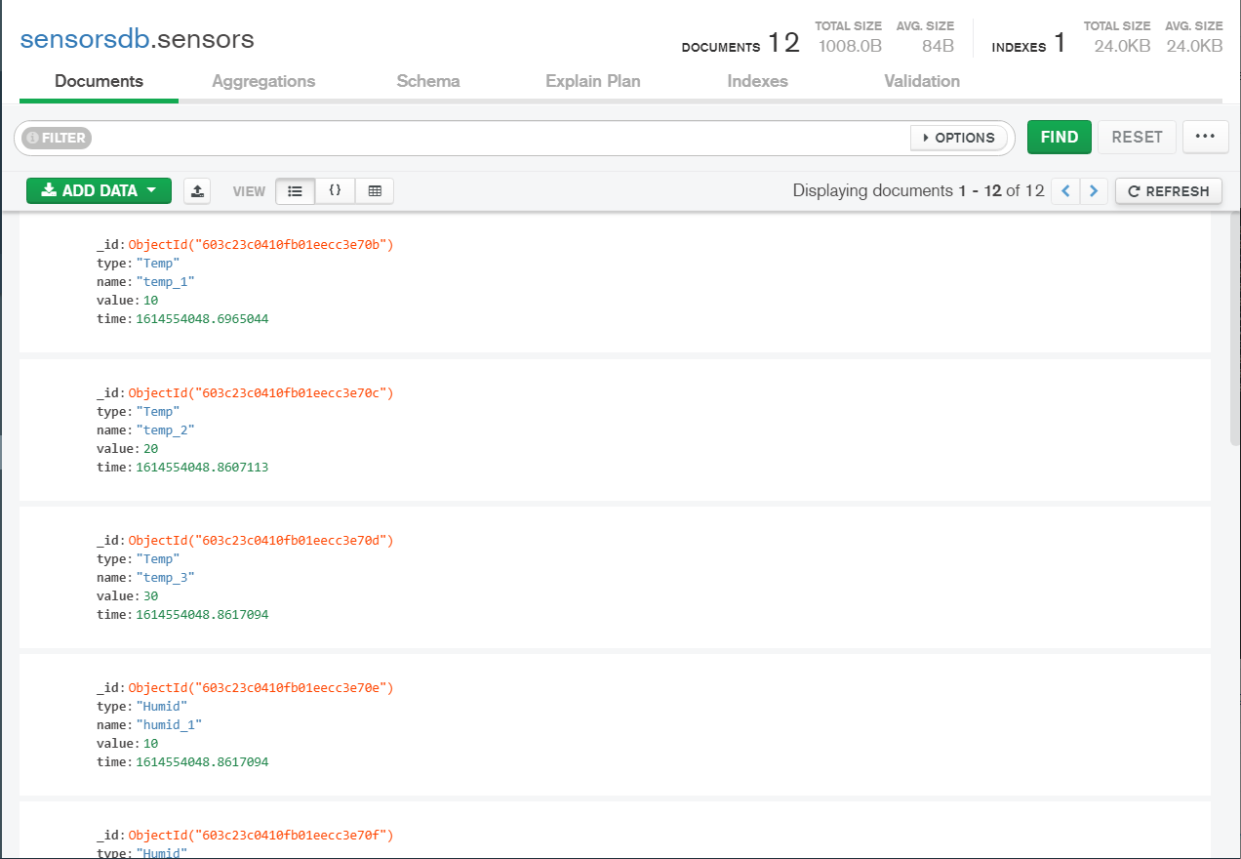
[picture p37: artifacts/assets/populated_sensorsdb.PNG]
populated
|  9  | Click the second collection named *sensors*.| The database should now be populated with the sensor data sent in the testing file. |

# Database Maximum Certified Usage
## [U021] As a property owner, I want to have a history for up to 100 sensors over a time period of one year so that, I may look back on trends in my historical sensor data.
## Description
This procedure will test the stability of the database and certify the ability to contain data to satisfy the following maximum specifications guidelines:

* 100 individual sensors
* Polling rate of all sensors is once per minute
* 1 year of data (45,000) entries must be searchable in less than 30 seconds

Note: The systems preformed nominally under these conditions and likely has the capability to scale beyond these guidelines.

## Test Tools and Dependencies
For this test, we are beginning with the following tools installed:
* Linux Text Editor (Or Similar Code Editing Tool)
* Linux Command Line
* Raspberry Pi 4 8gb running Ubuntu 20.10

We will also need the following test scripts:
* [Database_stressAdd_1000.py](/testing/Manual_Testing/Database_Stress_Test/Database_stressAdd_1000.py)
* [Database_stressSearch.py](/testing/Manual_Testing/Database_Stress_Test/Database_stressSearch.py)
* [Database.py](/testing/Manual_Testing/Database_Stress_Test/Database.py)
* [Sensors.py](/testing/Manual_Testing/Database_Stress_Test/Sensors.py)

## Test Case
**Test Status:** *PASS*

**Note:** The steps in this procedure should be carried out on a Raspberry Pi as specified in Tools for this section.
| No. | Steps to Reproduce | Expected Behavior |
| --- | --- | --- |
| 1 | Download all source scripts and place them in the same folder together | All source scripts needed for testing will be in the same directory |
| 2 | Open the directory containing all source scripts for this test | A directory listing all source files shall appear on the user's screen |
| 3 | Right click in the folder window with the testing source files and select *open in terminal* from the context menu | A terminal window shall open and display the correct file path next to the user's username |
| 4 | Type *python3 Database_stressAdd_1000.py* and press return | The script shall begin populating the database. This may take approx. 170 minutes |
| 5 | Once the script from step 4 has finished running type *time python3 Database_stressSearch.py* and press return | The average value for one sensor of the database shall be calculated representing a technical worst case for access time |
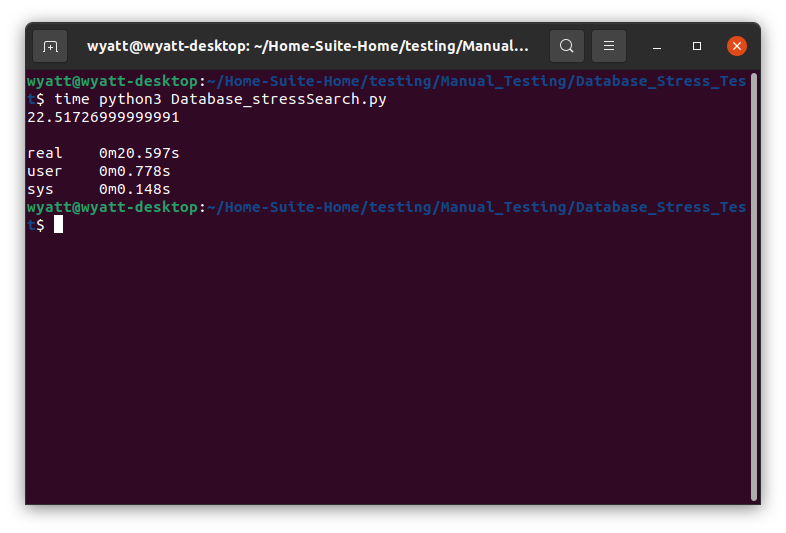
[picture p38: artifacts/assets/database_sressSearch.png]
searchTime
| 6 | Observe the *real* time printed in the terminal window and ensure that time is less than 60 seconds | The *real* time the Database took to return the average value will be less than 60 seconds  |

# Sensor Configurations in the Database
## [U019] As a property owner, I would like to save my sensor preferences so that, I only have to enter the information for each sensor once.

## Description
This procedure will demonstrate manually loading and retrieving the user settings configurations for each sensor.

## Test Tools and Dependencies
For this test, we are beginning with the following tools installed:
* Linux Text Editor (Or Similar Code Editing Tool)
* Linux Command Line
* Raspberry Pi 4 8gb running Ubuntu 20.10

We will also need the following test scripts:
* [databse_config_populate.py](/testing/Manual_Testing/Sample_Database/databse_config_populate.py)
* [database_read_configs.py](/testing/Manual_Testing/Sample_Database/database_read_configs.py)
* [Database.py](/source/Server_Component/Database.py)

## Test Case
**Test Status:** *PASS*
| No. | Steps to Reproduce | Expected Behavior |
| --- | --- | --- |
| 1 | Open the directory containing all three source scripts for testing | A directory containing the scripts we are using for this test will appear |
| 2 | Right click in the directory and select *open in terminal* from the context menu | A terminal window with the correct file path next to the user's username will appear |
| 3 | Type *python3 databse_config_populate.py* and press return | The script should compile and run without any errors |
| 4 | Once the script in step 3 has finished running, type *python3 database_read_configs.py* | all of the configuration data added in the previous step will be printed to the terminal |

# sensor_driver.py
## [U022] As a homeowner, I want multiple temperature and humidity sensors to save their readings so that, I can retain the historical environment data around my property.

## Description
This procedure will demonstrate the capability to save sensor data to the database at a regular interval.

## Test Tools and Dependencies
For this test, we are beginning with the following tools installed:
* Linux Text Editor (Or Similar Code Editing Tool)
* Linux Command Line
* A database loaded with sensor configurations
* A set of sensors

We will also need the source code:
* [sensor_driver.py](/source/sensor_driver.py)

## Test Case
**Test Status:** *PASS*
| No. | Steps to Reproduce | Expected Behavior |
| --- | --- | --- |
| 1 | Open the directory containing the source file | A directory containing *sensor_driver.py* will appear |
| 2 | Right click in the directory containing the source file for testing and select *open in terminal* from the context menu | A terminal window with the correct file path displayed next to the user's username will appear |
| 3 | Type *python3 sensor_driver.py* and press return | *sensor_driver.py* will compile and run |
| 4 | Observe the printouts to the terminal windows | each time a sensor is accessed and recorded, a printout containing the senor name and value to record is displayed in the terminal window |
| 5 | The script will loop every 60 seconds gathering data until we interrupt it - press *ctrl + c* to stop the script | The terminal window will return control to the user showing the test has ended |

# encryption.py
## [U028] As a property manager, I want my email credentials to be encrypted so that, my password stays secure.

## Description
This procedure will demonstrate the ability of encryption.py to store and retrieve an email and username as encrypted data.

## Test Tools and Dependencies
For this test, we are beginning with the following tools installed:
* Linux Command Line

We will also need the source code:
* [encryption.py](/source/encryption.py)

## Test Case
**Test Status:** *PASS*
| No. | Steps to Reproduce | Expected Behavior |
| --- | --- | --- |
| 1 | Open the directory containing the source file | A directory containing *encryption.py* will appear |
| 2 | Right click in the directory containing the source file for testing and select *open in terminal* from the context menu | A terminal window with the correct file path displayed next to the user's username will appear |
| 3 | Type *python3 encryption.py* and press return | *encryption.py* will compile and run |
| 4 | Observe the plain text printout in the terminal of the email and username for our development email account | an email and password shall be printed indicating the system successfully saved and retrieved the user credentials |
| 5 | Reopen the directory containing the *encryption.py* source file and observe the existence of a *.config* and *.key* file | the files with specified suffixes shall be present |
| 6 | Open both *.config* and *.key* files and observe their contents | the contents shall be incomprehensible strings of characters indicating the data within them has been encrypted |

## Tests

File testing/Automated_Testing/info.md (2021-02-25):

In order to run automated testing, this unit test source code must be placed on the same directory as the target code on your local device. 
Otherwise, pytests will not be discovered and will cause errors in all tests.

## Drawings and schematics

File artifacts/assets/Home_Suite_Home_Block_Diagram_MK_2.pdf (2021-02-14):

# TIncominglomand-lseiryeerreep.rs#Yjendts

All sensor data t.fi/TiceW-goatgoino#tJAIerttouse- External | ex : | temperature too low

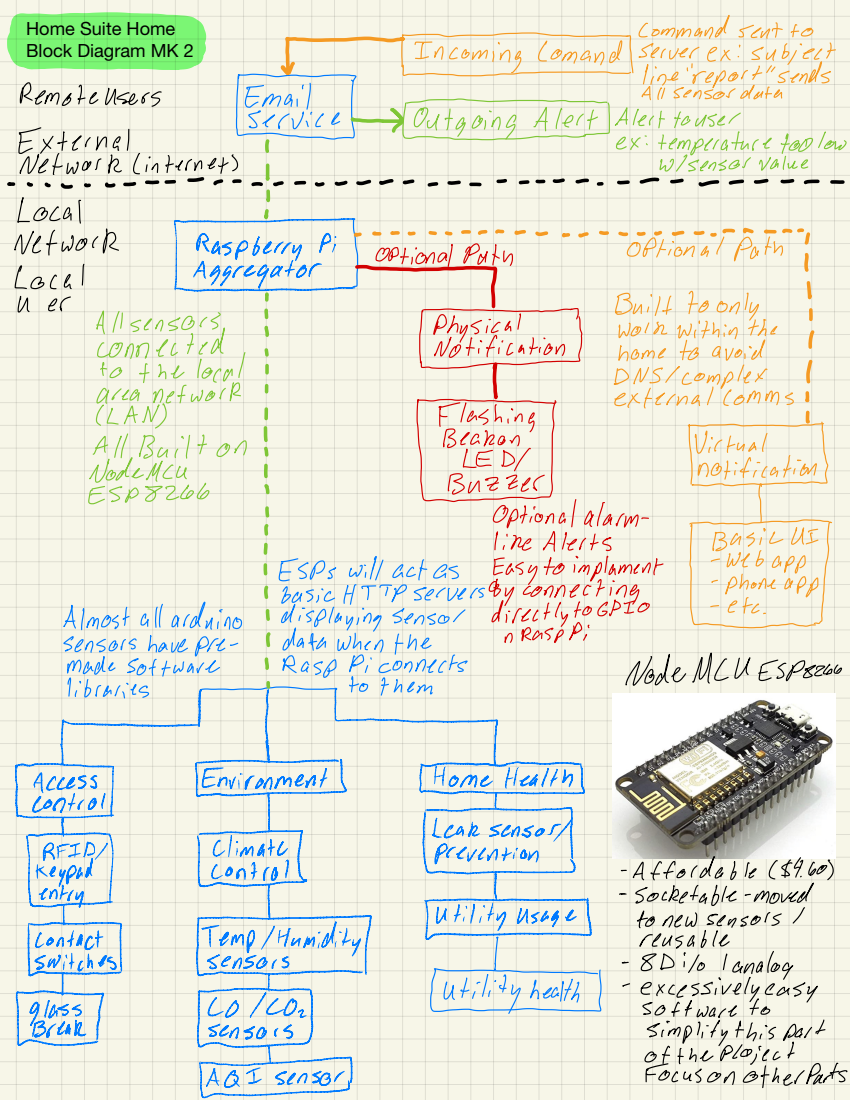
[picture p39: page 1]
Block Diagram MK 2; Command sent; Remote Users; Network; ( internet); wlsensor value; Local; Raspberry; Pi ) optional path; optional path; lAggregaT; Built; to only; All; sensors; physical; work; within; the; connected; Notification; home; avoid; local '; DNSIcomplex; area; network; external; comms; ; (LAN); flashing '; Beaton; Esp; au!deBn%; EMU Buzzer; thirotfiafqtionn ,; optional; line; Alerts; alarm-; Basil; ESPS will act as; Easy to implement; web; app; Almost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

Home Suite Home

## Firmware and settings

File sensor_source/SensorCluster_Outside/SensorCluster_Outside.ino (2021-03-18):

//
//  Filename: SensorCluster_Outside.ino
//  Date: 03/04/2021
//
//  Engineer: Wyatt Vining
//  Contact: wyatt.vining@knights.ucf.edu
//
//  Note: Enginnering asset - Not for production use 
//  
//  Hardware Configuration:
//    - DS18B20 Temperature Sensor x5
//    - SHT31 Temperature and Humidity Sensor x1
//    - DHT22 Temperature and Humidity Sensor x2
//
//  Description:
//    This is a cluster of sensors we are using for two purposes:
//      1. Hardware validation 
//      2. Standard database creation for those who do not have direct hardware access
// 

#include <math.h>

// DS18 Libraries
#include <OneWire.h>
#include <DallasTemperature.h>

// NodeMCU V12E Libraries 
#include <ESP8266WiFi.h>
#include <WiFiClient.h>
#include <ESP8266WebServer.h>

// SHT31 Sensor and I2C Libraries
#include <Wire.h>
#include "Adafruit_SHT31.h"

// DHT22 library
#include <DHT.h>

// DS18 Bus Pin
#define ONE_WIRE_BUS D6

// DHT22 constants
#define DHTTYPE DHT22
#define dhtpin1 D4
#define dhtpin2 D5

// wifi username and password
#include "creds.h"

// Lux Sensor
#define luxPin A0
#define REF_VOLTS 3.3
#define VOLTS_CONSTANT 0.003222656 // 3.3 / 1024
const double k = 3.3 / 1024.0;
const double luxFactor = 500000;
const double R2 = 10000;
const double B = 1.3 * pow(10.0, 7);
const double m = -1.4;

// DS18 Init
OneWire oneWire(ONE_WIRE_BUS);
DallasTemperature DS(&oneWire);

// DHT 22 init
DHT dht1(dhtpin1, DHTTYPE);
DHT dht2(dhtpin2, DHTTYPE);

// Declare a global object for temperature / humidity sensor
Adafruit_SHT31 sht31 = Adafruit_SHT31();

// SSID and Password of your WiFi router
const char* ssid = "NETWORK_NAME";
const char* password = "NETWORK_PASSWORD";

// Declare a global object variable from the ESP8266WebServer class
ESP8266WebServer server(80); //Server on port 80 - Standard for HTTP

// DS18 Addresses
uint8_t sensor1[8] = {0x28, 0x74, 0xB5, 0x07, 0xD6, 0x01, 0x3C, 0x50};
uint8_t sensor2[8] = {0x28, 0x66, 0xCE, 0x07, 0xD6, 0x01, 0x3C, 0x78};
uint8_t sensor3[8] = {0x28, 0x29, 0x50, 0x07, 0xD6, 0x01, 0x3C, 0x3C};
uint8_t sensor4[8] = {0x28, 0xCB, 0x97, 0x07, 0xD6, 0x01, 0x3C, 0x08};
uint8_t probe[8] = {0x28, 0x9F, 0xBA, 0x07, 0xD6, 0x01, 0x3C, 0xEE};


void setup() 
{
    Serial.begin(57600);

    WiFi.begin(ssid, password);     //Connect to your WiFi router
    Serial.println("");

    Serial.println(ssid);

    // loop until connection successful
    while (WiFi.status() != WL_CONNECTED) 
    {
        delay(500); // wait half a second before retrying connection 
        Serial.print(".");
    }

    //If connection successful show IP address in serial monitor
    Serial.println("");
    Serial.print("Connected to ");
    Serial.println(ssid);
    Serial.print("IP address: ");
    Serial.println(WiFi.localIP());  //IP address assigned to your ESP

    // add HTTP plugs and the functions that support the command
    server.on("/", handleRoot); // handle if the root address is accessed - this is an error
    server.on("/temperatureSHT", handleTemperatureSHT); // handle a request for sensor data
    server.on("/humiditySHT", handleHumiditySHT); // handle a request for sensor data
    server.on("/sensor1", handleTemperatureSensor1);
    server.on("/sensor2", handleTemperatureSensor2);
    server.on("/sensor3", handleTemperatureSensor3);
    server.on("/sensor4", handleTemperatureSensor4);
    server.on("/probe", handleTemperatureProbe);
    server.on("/dht1temperature", handleTemperatureDHT1);
    server.on("/dht2temperature", handleTemperatureDHT2);
    server.on("/dht1humidity", handleHumidityDHT1);
    server.on("/dht2humidity", handleHumidityDHT2);
    server.on("/lux", handleLux);

    // Open the server for requests
    server.begin();
    Serial.println("HTTP server started");

    // Start Temperature / Humidity Sensor 
    Serial.println("SHT31 test");
    
    if (! sht31.begin(0x44)) // Set to 0x45 for alternate i2c addr - Needed for two temp sensors 
    {   
        Serial.println("Couldn't find SHT31");
    }
    
    DS.begin();

    dht1.begin();
    dht2.begin();
}

void loop() 
{
    // handle a client request - direct the clients to the page they request using server.on() above
    server.handleClient(); 

}


// This page will display if the ip address is accessed with no HTTP plug 
void handleRoot() 
{
   Serial.println("Root page reached");
   String s = "rootPage\n";
   server.send(200, "text/html", s); // server.send(RESPONSE(should be 200), TYPE(Arbitrary data type), STRING(to be sent))
}


void handleTemperatureDHT1()
{
    String tempC = String(dht1.readTemperature(false), 2);
    Serial.print("DHT22 sensor 1 temp C: ");
    Serial.println(tempC);
    server.send(200, "text/html", tempC);
}


void handleTemperatureDHT2()
{
    String tempC = String(dht2.readTemperature(false), 2);
    Serial.print("DHT22 sensor 2 temp C: ");
    Serial.println(tempC);
    server.send(200, "text/html", tempC);
}


void handleHumidityDHT1()
{
    String humidity = String(dht1.readHumidity(), 2);
    Serial.print("DHT22 sensor 1 humidity: ");
    Serial.println(humidity);
    server.send(200, "text/html", humidity);
}


void handleHumidityDHT2()
{
    String humidity = String(dht2.readHumidity(), 2);
    Serial.print("DHT22 sensor 2 humidity: ");
    Serial.println(humidity);
    server.send(200, "text/html", humidity);
}


// this page will be reached if the HTTP plug is "/temperature"
void handleTemperatureSHT() 
{ 
     Serial.println("Temperature request recieved");
     String temp = String(getTemp());
     server.send(200, "text/html", temp); // server.send(RESPONSE(should be 200), TYPE(Arbitrary data type), STRING(to be sent))
}


void handleTemperatureSensor1()
{
    DS.requestTemperatures();
    double tempC = (double)DS.getTempC(sensor1);
    Serial.print("DS Sensor 1: ");
    Serial.println(tempC);
    String celcius = String(tempC);
    server.send(200, "text/html", celcius);
}

void handleTemperatureSensor2()
{
    DS.requestTemperatures();
    double tempC = (double)DS.getTempC(sensor2);
    Serial.print("DS Sensor 2: ");
    Serial.println(tempC);
    String celcius = String(tempC);
    server.send(200, "text/html", celcius);
}


void handleTemperatureSensor3()
{
    DS.requestTemperatures();
    double tempC = (double)DS.getTempC(sensor3);
    Serial.print("DS Sensor 3: ");
    Serial.println(tempC);
    String celcius = String(tempC);
    server.send(200, "text/html", celcius);
}


void handleTemperatureSensor4()
{
    DS.requestTemperatures();
    double tempC = (double)DS.getTempC(sensor4);
    Serial.print("DS Sensor 4: ");
    Serial.println(tempC);
    String celcius = String(tempC);
    server.send(200, "text/html", celcius);
}


void handleTemperatureProbe()
{
    DS.requestTemperatures();
    double tempC = (double)DS.getTempC(probe);
    Serial.print("DS Sensor probe: ");
    Serial.println(tempC);
    String celcius = String(tempC);
    server.send(200, "text/html", celcius);
}


// this page will be reached if the HTTP plug is "/humidity"
void handleHumiditySHT()
{
    Serial.println("Humidity Request Recieved");
    double humidity = (double)sht31.readHumidity();
    String humidityStr = String(humidity, 2);
    server.send(200, "text/html", humidityStr); // server.send(RESPONSE(should be 200), TYPE(Arbitrary data type), STRING(to be sent))
} 


void handleLux()
{
    Serial.println("Lux Requested.");
    String lux = String(getLux());
    Serial.print("Lux: ");
    Serial.println(lux);
    server.send(200, "text/html", lux);
}


double getLux()
{
    double V2 = k * analogRead(luxPin);
    double R1 = (REF_VOLTS / V2 - 1) * R2;
    double lux = B * pow(R1, m);
    return lux;
}


// returns the current temperature in degrees celcius
double getTemp()
{
    // get the temperature from the sensor
    double temperature = (double)sht31.readTemperature(); // The default value is a float - we cast as a double for efficiency

    // check if the temperature was read properly - this is unnecessary for the sensor but useful for debugging 
    if (! isnan(temperature))
    {
        Serial.print("Temperature: ");
        Serial.print(temperature);
        Serial.println("C");
    }
    else
    {
        Serial.println("Failed to read temperature");
    }

    return temperature; // will return nan if there is an issue with the sensor
}


// returns the current relative humidity percentage
int getHumidity()
{
    // get the relative humidity from the sensor 
    double humidity = (double)sht31.readHumidity(); // float is the default - cast as an int since the accuracy for the sensor is only out to the tens deciamal anyway

    // check if humidity was read from the sensor properly
    if (! isnan(humidity))
    {
        Serial.print("Humidity: ");
        Serial.print(humidity);
        Serial.println("%");
    }
    else
    {
        Serial.println("Failed to read temperature");
    }

    return humidity; // will return nan if there is an issue with the sensor
}

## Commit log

2021-02-11 Create sensors source
2021-02-11 Update Temperature_Humidity_HelloWorld.ino
    This is the code for the first sensor and a framework for future sensors.
2021-02-11 Update Temperature_Humidity_HelloWorld.ino
    Updated comments.
2021-02-11 Add files via upload
    This is the code for the first sensor and a framework for all sensors in this project.
2021-02-11 Couple more Desing doc edits.
2021-02-16 Update README.md
    Sprint 3 materials created
2021-02-19 updated Sensor constructor
2021-02-19 added sensor readings
2021-02-20 updated Sensors() import
2021-02-24 initial sensor cards
2021-02-24 initial css for sensor card
2021-02-24 Updated error handling in Sensors.py
2021-02-26 added ability to see and refresh sensor's value on each card
2021-02-28 Added functionality for config data for sensors
2021-03-04 Add Engineering Assets for Sensor Hardware and Software Validation
2021-03-04 Add function to poll sensors in config every 60 seconds
2021-03-04 Add sensor testbed for indoor sensors
2021-03-04 Add testbed for outdoor sensors
2021-03-04 Add manual sensor config
2021-03-05 can create sensors as cards
2021-03-05 Add sample database in JSON format - Temporary Timestamps
2021-03-05 Add sample database in CSV format - Temporary Timestamps
2021-03-06 adds error printout for url creation exception
2021-03-06 Adds sys.path for imports to sensorPoll
2021-03-06 updated print statement
2021-03-06 Adds test DB to samples
    [testdb.csv]
2021-03-06 Adds defaults for sensor()
2021-03-06 Updates to testdb samples
    [testdb.csv]
2021-03-06 Removes outdated sample databases
2021-03-06 Adds new format for sensor configs
2021-03-06 Updates min and max thresholds for outdoor humidity sensors
2021-03-06 First version of sensor_driver
2021-03-07 added get sensor data manual test procedure
2021-03-07 added quick links to source, testing, sensor source
2021-03-07 changed sensor source to sensor_source for easier linkage
2021-03-07 Adds user story and ID to sensors.py manual testing
2021-03-07 Adds manual testing utility for reading sensor configs
2021-03-07 Adds manual testing procedure for sensor configurations in the database
2021-03-07 Adds manual test procedure for sensor_driver.py
2021-03-08 updates sensor source code folder
2021-03-09 Adds ability to connect to UI from any device on the local network
2021-03-10 refactored sensor data response and added Line_Graph module in Analytics Component
2021-03-11 updates folder structure in sensor source to be compatible with arduino IDE
2021-03-11 Adds header file for user to enter wifi credentials for arduinos
2021-03-14 Adds method to return current timestamp as a string
2021-03-14 Adds alerts.py for handling user alerts for sensor out of tollerance events
2021-03-14 Adds class diagram for Sensors.py
2021-03-14 Updates Sensors_class_diagram.png
2021-03-14 Updates Sensors class diagram
2021-03-14 Removed unnnessecary print statements
2021-03-14 added print statements for clarity
2021-03-14 sensors json file to help with mocking database connection for automated testing
2021-03-14 Updated sensor test with new parameter 'url_plug'
2021-03-16 groundwork for edit card
2021-03-16 initial graph buttons to Linegraph.py
2021-03-17 more groundwork for editing cards
2021-03-18 Adds a utility for converting units of supported sensor types
2021-03-18 Adds unit conversion for supported sensor types
2021-03-18 Adds rounding to temperature conversion result
2021-03-18 Initial commit of light intensity (LUX) sensor
2021-03-18 Updates light intensity sensor to connect to the network - finalizes lux calculations
2021-03-18 Adds lux sensor to outside sensor cluster - updates creds headers
2021-03-18 Fixes tired me's spelling errors
2021-03-18 Adds leak detecting sensor
    [leak_detector.ino]
2021-03-19 finished graph buttons
2021-03-20 Adds 3D model of barometeric sensor housing
    [barometeric_sensor - Bottom^barometeric_sensor-1.STL, barometeric_sensor - Lid^barometeric_sensor-1.STL]
2021-03-20 Adds bmp180 barometer, temperature, altimeter sensor
2021-03-20 Adds template to quickly create ESP sensors
2021-03-20 Adds conversions for pressure -- simplifies unit comparison by changing units to lowecase
2021-03-21 printing help
2021-03-21 Used to populate the sample database
2021-03-21 mapping config with sensors collection + indexing
2021-03-22 Adds housing for AQI / CO2 sensor
    [box^CO2_AQI_sensor.STL, lid^CO2_AQI_sensor.STL]
2021-03-22 Adds 3d model for leak detector
    [Lid^leak_detector.STL, base^leak_detector.STL]
2021-03-23 Adds flow and temperature probe housing
    [box^flow_temp.STL, lid^flow_temp.STL]
2021-03-23 Adds cuts for screws in box
    [box^flow_temp.STL]
2021-03-24 adds CO2 and TVOC sensor - air quality
2021-03-24 Fixes bug when checking if the sensorValue is a number
2021-03-24 Adds mbar, hpa, and inHg to pressure conversions -- Bug Fixes
2021-03-26 Adds 3d model for SHT31D Temperature and Humidity Sensor
    [box^SHT31_Temperature_Humidity.STL, lid^SHT31_Temperature_Humidity.STL]
2021-03-27 Adds SHT31-D Temperature and Humidity Sensor
2021-03-27 Adds experimental version of SHT31 sensor housing for better waste heat management
    [box^SHT31_extended.STL, lid^SHT31_extended.STL]
2021-03-27 Adds temperature probe ssensor
2021-03-28 added no device email checking
